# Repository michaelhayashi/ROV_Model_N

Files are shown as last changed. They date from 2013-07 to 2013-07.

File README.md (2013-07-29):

ROV_Model_N
===========

Purdue IEEE ROV Team project files

All of the electrical and code files are provided here free of charge for enthusiasts to modify, hack, fix, and do whatever to under OSHW. All files are given without any guarantee.

If anyone does have a cool idea about how to reuse/repurpose any of this hardware, or notices any glaring issues with it, let us know at purduerov@gmail.com

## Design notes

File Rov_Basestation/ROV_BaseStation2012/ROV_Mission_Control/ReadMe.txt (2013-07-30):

========================================================================
    APPLICATION : ROV_Mission_Control Project Overview
========================================================================

AppWizard has created this ROV_Mission_Control Application for you.  

This file contains a summary of what you will find in each of the files that
make up your ROV_Mission_Control application.

ROV_Mission_Control.vcxproj
    This is the main project file for VC++ projects generated using an Application Wizard. 
    It contains information about the version of Visual C++ that generated the file, and 
    information about the platforms, configurations, and project features selected with the
    Application Wizard.

ROV_Mission_Control.vcxproj.filters
    This is the filters file for VC++ projects generated using an Application Wizard. 
    It contains information about the association between the files in your project 
    and the filters. This association is used in the IDE to show grouping of files with
    similar extensions under a specific node (for e.g. ".cpp" files are associated with the
    "Source Files" filter).

ROV_Mission_Control.cpp
    This is the main application source file.
    Contains the code to display the form.

Form1.h
    Contains the implementation of your form class and InitializeComponent() function.

AssemblyInfo.cpp
    Contains custom attributes for modifying assembly metadata.

/////////////////////////////////////////////////////////////////////////////
Other standard files:

StdAfx.h, StdAfx.cpp
    These files are used to build a precompiled header (PCH) file
    named ROV_Mission_Control.pch and a precompiled types file named StdAfx.obj.

/////////////////////////////////////////////////////////////////////////////

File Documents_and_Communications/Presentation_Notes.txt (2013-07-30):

CAUTION: The PowerPoint presentation is for practice purposes only! The presentation should be given extemporaneously using only the vehicle and binders as aids.

Schedule:
Judges Introduce Themselves
We Introduce ourselves individually
  Name
  Year (going in to)
  Years on team
  What "team" you worked on (electrical/mechanical/communications/etc)
Hand judges their binders

Presenter #1 (Team spokesperson)
  Introduction
  Mission Theme
  Intro to Model N
    "ground up for mission" speech
Presenter #2 (Co-lead ME)
  Manipulator
  Measuring Tool
  Turning Motors
  Thrusters
Presenter #3 (Co-lead ME)
  Electronics Box
  Frame
  Cameras
Presenter #4 (Mechanical assembler)
  Buoyancy & Ballast
  Tether
  Pneumatics
Presenter #5 (Hardware EE)
  Transmissometer
  Electronics
Presenter #6 (Coding CompE)
  Software
    Main board & Basestation
    GUI
Presenter #7 (Pilot & CompE)
  Software
    Controls & Piloting
Presenter *8 (Team Captain)
  Expenses
  Scheduling
  Safety
  Outreach
  Acknowledgements

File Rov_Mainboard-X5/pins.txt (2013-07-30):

Pins we maybe can't use
PC14	> to other external oscilator
PC15 

PA13	> swd programming pins
PA14

PB9	> Audio SCA & SCL
PB6 

PC7	
PC10	> i2s3 
PC12
PA4

PD4	> audio reset

PC3	> PDM out >Double check these!
PC4	

PC3	> PDM out
PB10	> CLk in

PA9	> USB OTG	
PA11
PA12
PA10

PC0	> OTG Power

PD5	> OTH Over current

PA0	> wake up button

PA7	> SPI1 mosi
PA5	> spi1 sck

PE3	>cs spi????????
PA6	> spi1 miso

PE0	> MEMS init
PE1

PD12	> Greeb Led
PD13	> Orange Led
PD14	> Red Led
PD15	> Blue Led

11:60 reduction

Pins we need for things (not specific)

Already on discovery 
SPI1 - onboard accelerometer SPI1: PA7, PA6, PA5, Enable x2: PE0, PE1, why PE3 is needed is unknown
NRST - already implemented - NRST
Debug Led - can use ones on dev board - PD12, PD13, PD14, PD15

Need to put on board
i2c1 - IMU  - PB8, PB7
4x GPIO - for water detection  - Input floating: PD0, PC12, PC11, PC10
1x PWM - Turner motors - TIM1: PE9, PE11, PE13, PE14 - May not need all!
2x GPIO - motor selection - Output push pull: PE8, PE7
1x GPIO for fuse blown - Input floating:PE10
SPI2 - for solenoid selection - SPI2: PB15, PB10, PD3, PD2
5x ADC - for power sensing - ADC1: PA1, PA4, PB0, PB1, PC5
2x uart - 1 for tether - Usart2: PD6, PA2 
Usart6: PC7, PC6 - Motor bus also need PC8, PC9
2x GPIO - for camera selection PC11, PC12

Pb5 for MOTOR DIR

4x Extra GIPO: PD7, PE6, PE4, PE2

296-22711-6-ND - shift register
BCV46

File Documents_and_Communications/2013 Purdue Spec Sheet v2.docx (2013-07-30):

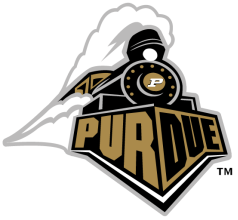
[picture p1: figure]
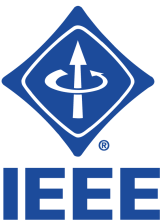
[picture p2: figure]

Purdue University IEEE ROV Team

West Lafayette, Indiana, USA

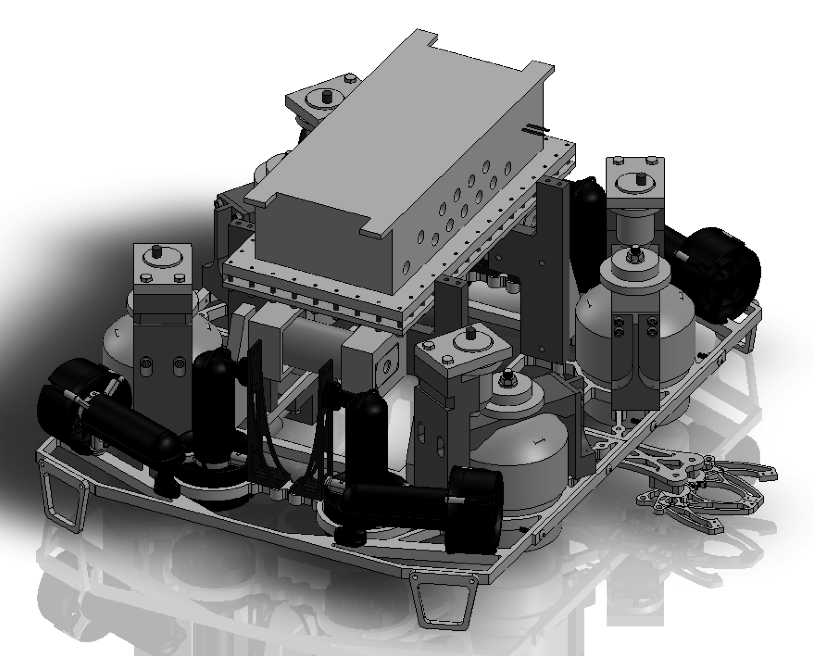
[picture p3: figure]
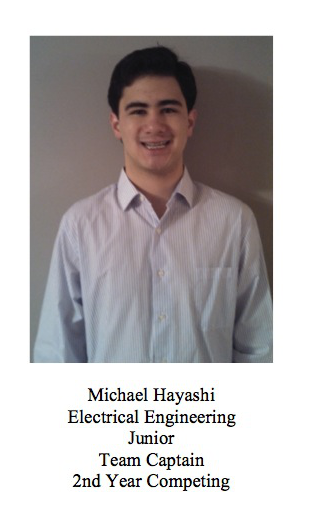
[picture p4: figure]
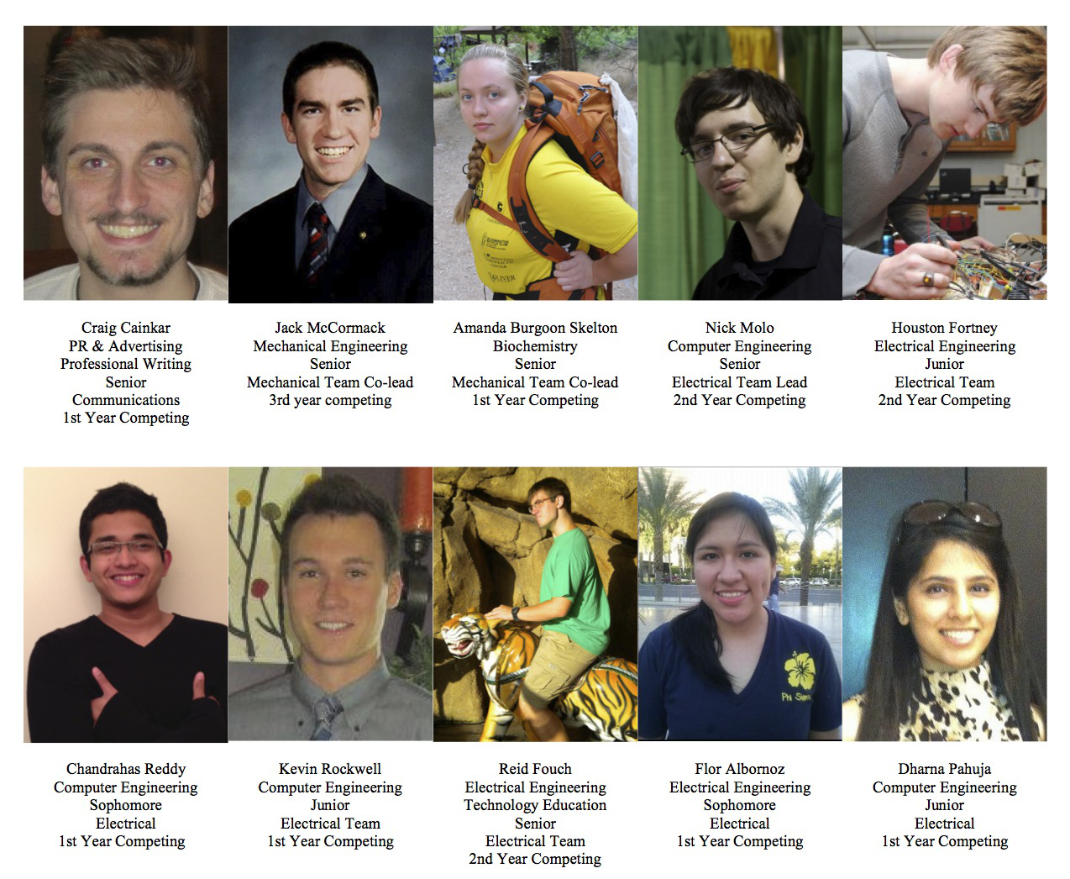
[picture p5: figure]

Total Cost of ROV: $20,758.90 USD Total Weight in Air: 19.0 kg

Overall Dimensions: 71 cm x 69 cm x 51 cm

Primary Materials: aluminum, stainless steel, polyoxymethylene (delrin), high-density polyethylene, polycarbonate

Special Features: immense power to weight ratio, lightweight MIC 6 aluminum frame, high-accuracy length measuring tool, single fixed manipulator for simplicity, entirely custom onboard electronics system and software

Key Safety Features: shrouds on all propellers, plastic propellers, complete FEA analysis with a safety factor of 2,

all electrical wiring sealed with liquid electrical tape and heat shrink, multiple fuses throughout electrical system, emergency quick release pneumatic valve

Model N

Distance Traveled: 2915 KM

Year Competing: 5th Year

2012 Finish: 2nd Place

Range of Grade Levels:

Sophmore to Senior

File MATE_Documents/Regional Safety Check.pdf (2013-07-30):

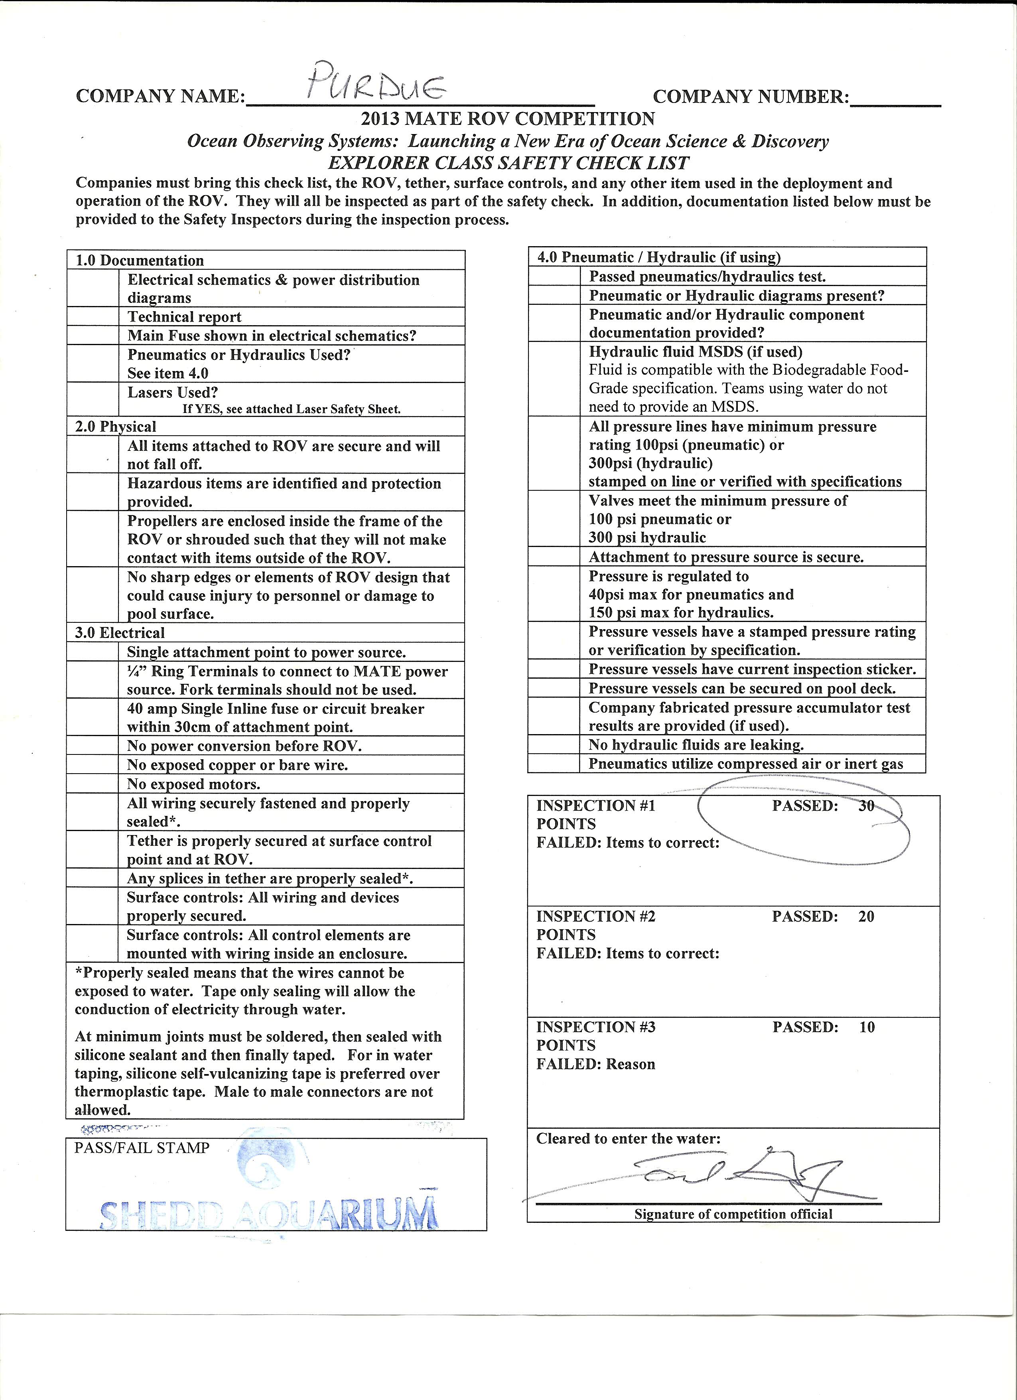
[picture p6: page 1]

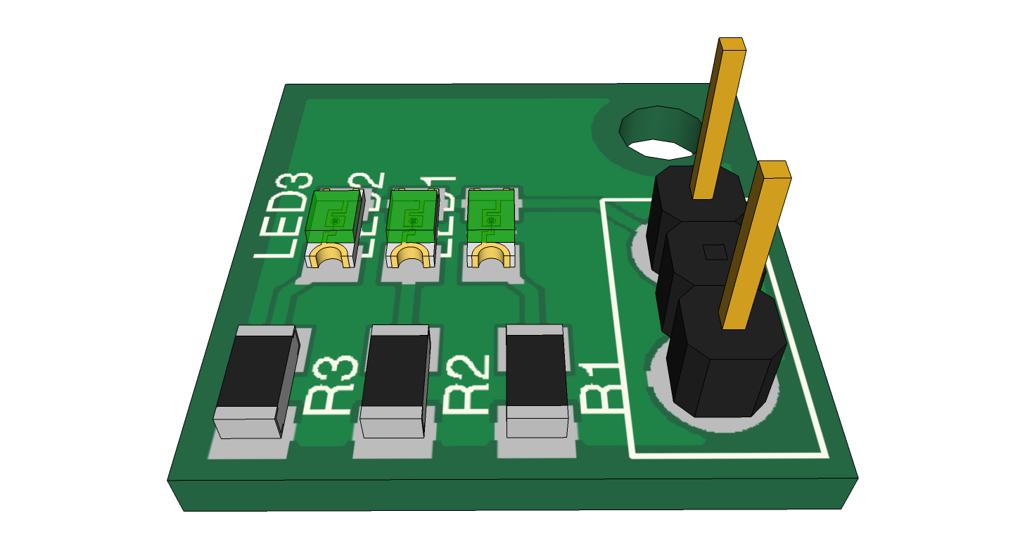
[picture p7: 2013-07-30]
Electronics/Transmissometer_TX_Board/TX Board.png

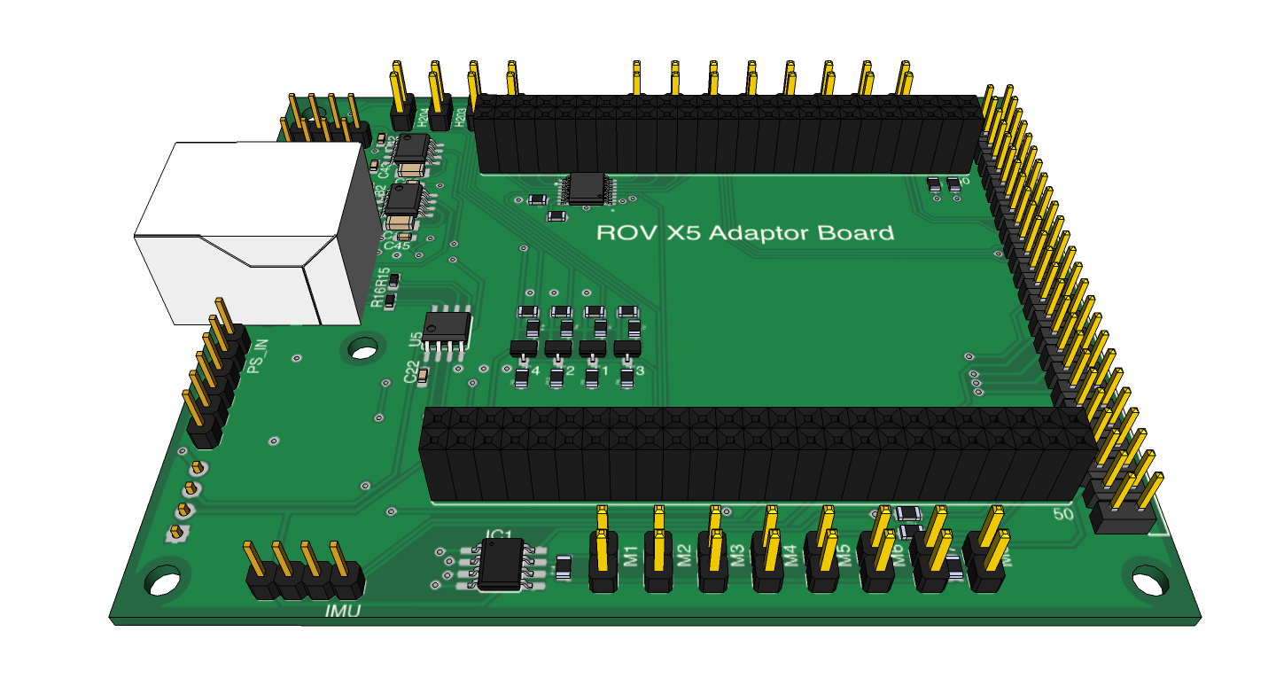
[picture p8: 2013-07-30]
Electronics/Microcontroller_Adaptor_Board/Adaptor.png

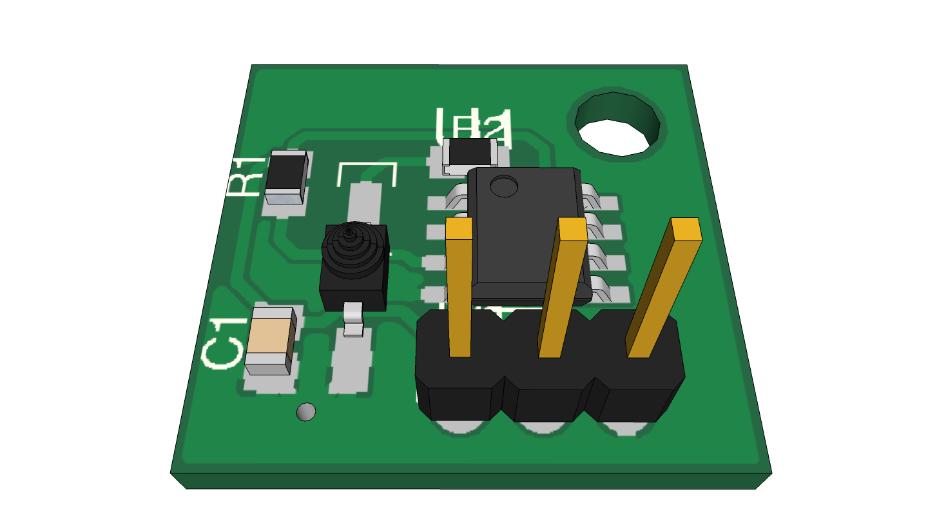
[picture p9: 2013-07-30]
Electronics/Transmissometer_RX_Board/Transmissometer_RX_Boardv1.png

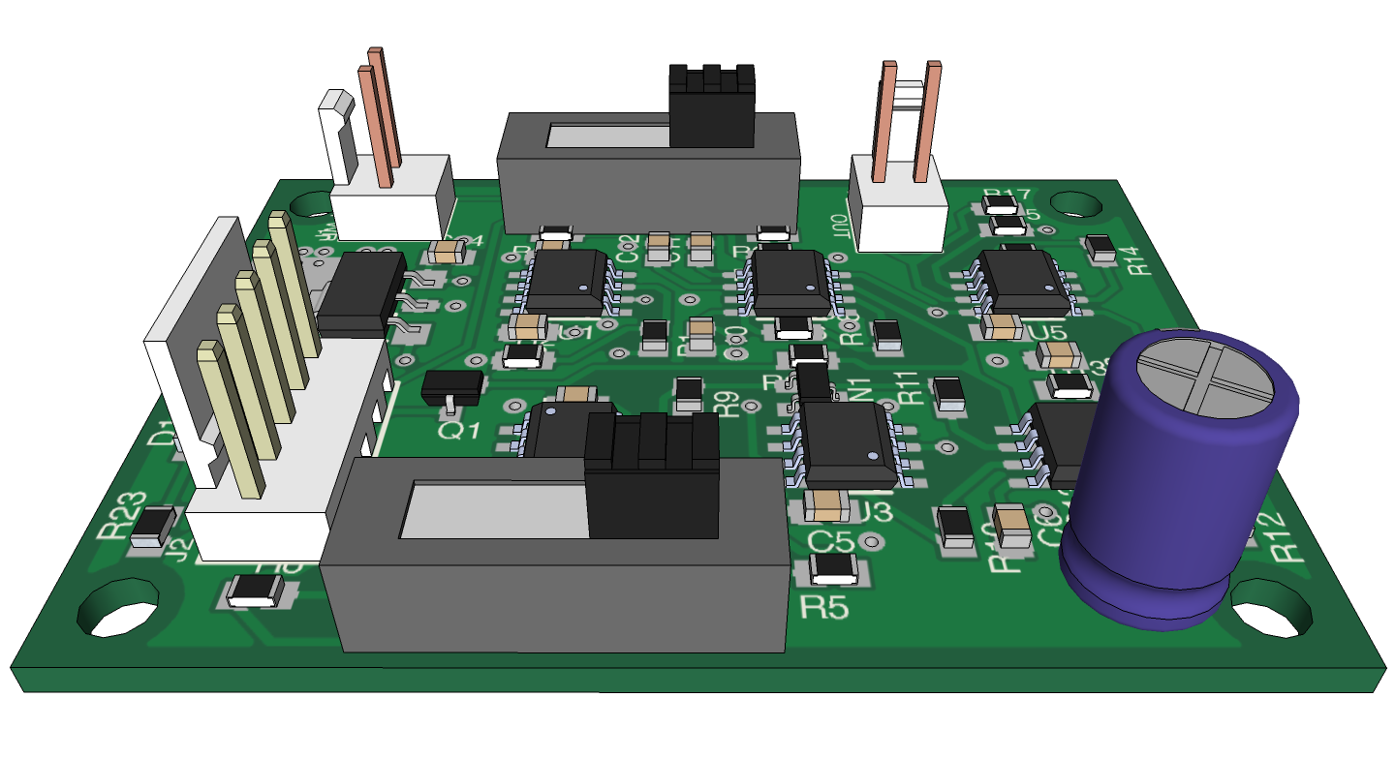
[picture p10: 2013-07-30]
Electronics/Transmissometer_Surface_Board/Top.png

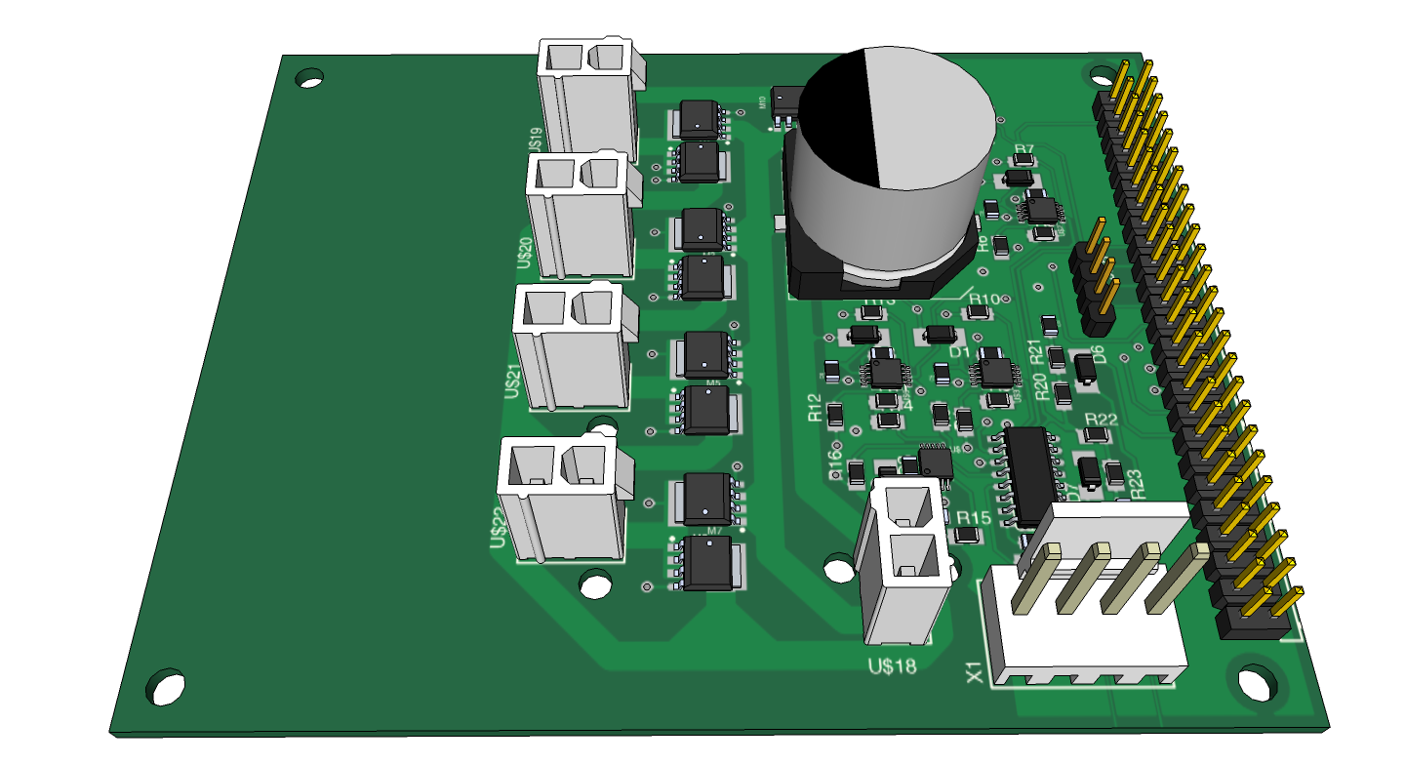
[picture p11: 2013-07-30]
Electronics/Application_Board/Application_Board.png

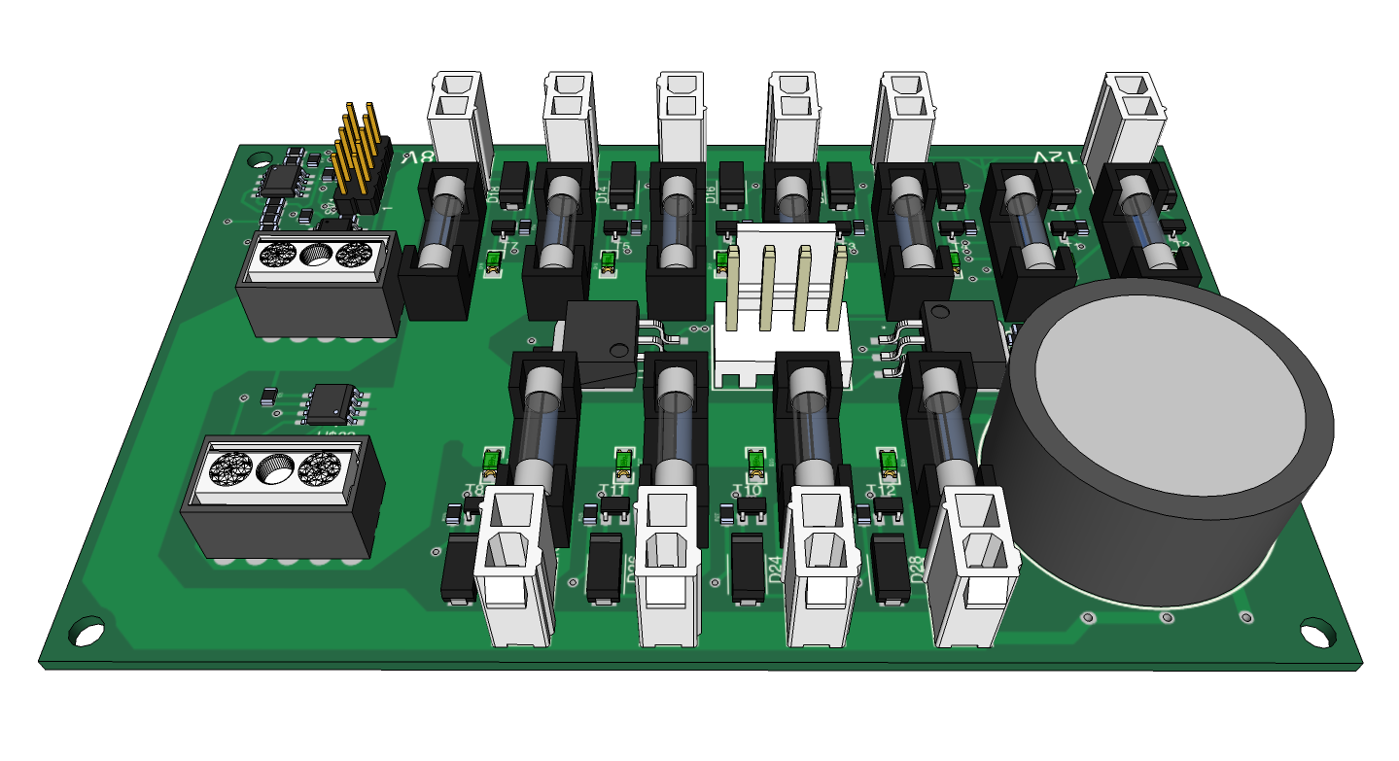
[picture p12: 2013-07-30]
Electronics/Power_Board/Power Board.png

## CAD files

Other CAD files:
Electronics/Application_Board/Application_Board.skp
Electronics/Microcontroller_Adaptor_Board/Adaptor.skp
Electronics/Power_Board/Power Board.skp
Electronics/ROV_2013_SketchUp/0805.skp
Electronics/ROV_2013_SketchUp/0805~.skp
Electronics/ROV_2013_SketchUp/10-MSOP.skp
Electronics/ROV_2013_SketchUp/10-MSOP~.skp
Electronics/ROV_2013_SketchUp/1X02.skp
Electronics/ROV_2013_SketchUp/1X02_XTRA_BIG.skp
Electronics/ROV_2013_SketchUp/1X02_XTRA_BIG~.skp
Electronics/ROV_2013_SketchUp/1X02~.skp
Electronics/ROV_2013_SketchUp/1X03.skp
Electronics/ROV_2013_SketchUp/1X04.skp
Electronics/ROV_2013_SketchUp/1X04_NO_SILK.skp
Electronics/ROV_2013_SketchUp/1X04~.skp
Electronics/ROV_2013_SketchUp/1X06.skp
Electronics/ROV_2013_SketchUp/1X06~.skp
Electronics/ROV_2013_SketchUp/2-3SW.skp
Electronics/ROV_2013_SketchUp/2-3SW~.skp
Electronics/ROV_2013_SketchUp/22-23-2021.skp
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

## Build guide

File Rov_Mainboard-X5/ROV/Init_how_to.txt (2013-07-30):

1. Port RCC

RCC_AHB1PeriphClockCmd(RCC_AHB1Periph_GPIOX, ENABLE);

2. Periph RCC

 - Tim
	RCC_APB1PeriphClockCmd(RCC_APB1Periph_TIMX, ENABLE );
	RCC_APB2PeriphClockCmd(RCC_APB2Periph_TIM9, ENABLE ); //TIM9 and TIM8 are on APB2

 - USART
	RCC_APB1PeriphClockCmd(RCC_APB1Periph_USART3, ENABLE);

3. GPIO Enable

 - PWM
	GPIO_InitTypeDef GPIO_InitStructure;
	
	GPIO_InitStructure.GPIO_Pin =  GPIO_Pin_X;// | GPIO_Pin_X //more for channels
	GPIO_InitStructure.GPIO_Mode = GPIO_Mode_AF;
	GPIO_InitStructure.GPIO_OType = GPIO_OType_PP;
	GPIO_InitStructure.GPIO_PuPd = GPIO_PuPd_NOPULL;
	GPIO_InitStructure.GPIO_Speed = GPIO_Speed_100MHz;
	
	GPIO_Init(GPIOX, &GPIO_InitStructure);

	GPIO_PinAFConfig(GPIOX, GPIO_PinSourceX, GPIO_AF_TIMX);// put in order of what channel it is
	GPIO_PinAFConfig(GPIOX, GPIO_PinSourceX, GPIO_AF_TIMX);

 - OUTPUT
	GPIO_InitTypeDef GPIO_InitStructure;

	GPIO_InitStructure.GPIO_Pin = GPIO_Pin_X;
        GPIO_InitStructure.GPIO_Mode = GPIO_Mode_OUT;
        GPIO_InitStructure.GPIO_OType = GPIO_OType_PP;
        GPIO_InitStructure.GPIO_PuPd = GPIO_PuPd_NOPULL;
	GPIO_InitStructure.GPIO_Speed = GPIO_Speed_100MHz;
	GPIO_Init(GPIOX, &GPIO_InitStructure);

 - INPUT
	//not figured out yet...

 - USART
	GPIO_InitTypeDef GPIO_InitStructure;

	GPIO_InitStructure.GPIO_Pin =  GPIO_Pin_X | GPIO_Pin_X;
	GPIO_InitStructure.GPIO_Mode = GPIO_Mode_AF;
	GPIO_InitStructure.GPIO_OType = GPIO_OType_PP;
	GPIO_InitStructure.GPIO_PuPd = GPIO_PuPd_NOPULL;
	GPIO_InitStructure.GPIO_Speed = GPIO_Speed_100MHz;
	GPIO_Init(GPIOX, &GPIO_InitStructure);

	GPIO_PinAFConfig(GPIOX, GPIO_PinSourceX, GPIO_AF_USART3); //note pretty much same as PWM
	GPIO_PinAFConfig(GPIOX, GPIO_PinSourceX, GPIO_AF_USART3); //Except for here

4. Timer enable

	PrescalerValue = //set something

	TIM_TimeBaseInitTypeDef TIM_TimeBaseInitStruct;
	
	TIM_OCInitTypeDef TIM_OCInitStruct;

	TIM_TimeBaseStructInit( &TIM_TimeBaseInitStruct );
	TIM_TimeBaseInitStruct.TIM_ClockDivision = TIM_CKD_DIV4;
	TIM_TimeBaseInitStruct.TIM_Period =1000 - 1;   // 0..999
	TIM_TimeBaseInitStruct.TIM_Prescaler = PrescalerValue; // Div 240
        TIM_TimeBaseInit( TIMX, &TIM_TimeBaseInitStruct );

        TIM_OCStructInit( &TIM_OCInitStruct );
	TIM_OCInitStruct.TIM_OutputState = TIM_OutputState_Enable;
	TIM_OCInitStruct.TIM_OCMode = TIM_OCMode_PWM1;
	TIM_OCInitStruct.TIM_Pulse = 500;

	TIM_OC1Init( TIMX, &TIM_OCInitStruct ); //will use 2 channels on all timers but tim 8, 
	TIM_OC2Init( TIMX, &TIM_OCInitStruct ); //in that case will use 3 (LED)
	TIM_OC3Init( TIMX, &TIM_OCInitStruct );

	TIM_Cmd( TIMX, ENABLE );
	
5. Periph Init
	USART_InitTypeDef USART_InitStructure;
	
	USART_InitStructure.USART_BaudRate = 9600;
	USART_InitStructure.USART_WordLength = USART_WordLength_8b;
	USART_InitStructure.USART_StopBits = USART_StopBits_1;
	USART_InitStructure.USART_Parity = USART_Parity_No;
	USART_InitStructure.USART_HardwareFlowControl = USART_HardwareFlowControl_None;
	
	USART_InitStructure.USART_Mode = USART_Mode_Rx | USART_Mode_Tx;
	
	USART_Init(USART3, &USART_InitStructure);

	USART_Cmd(USART3, ENABLE);

Shift register notes -

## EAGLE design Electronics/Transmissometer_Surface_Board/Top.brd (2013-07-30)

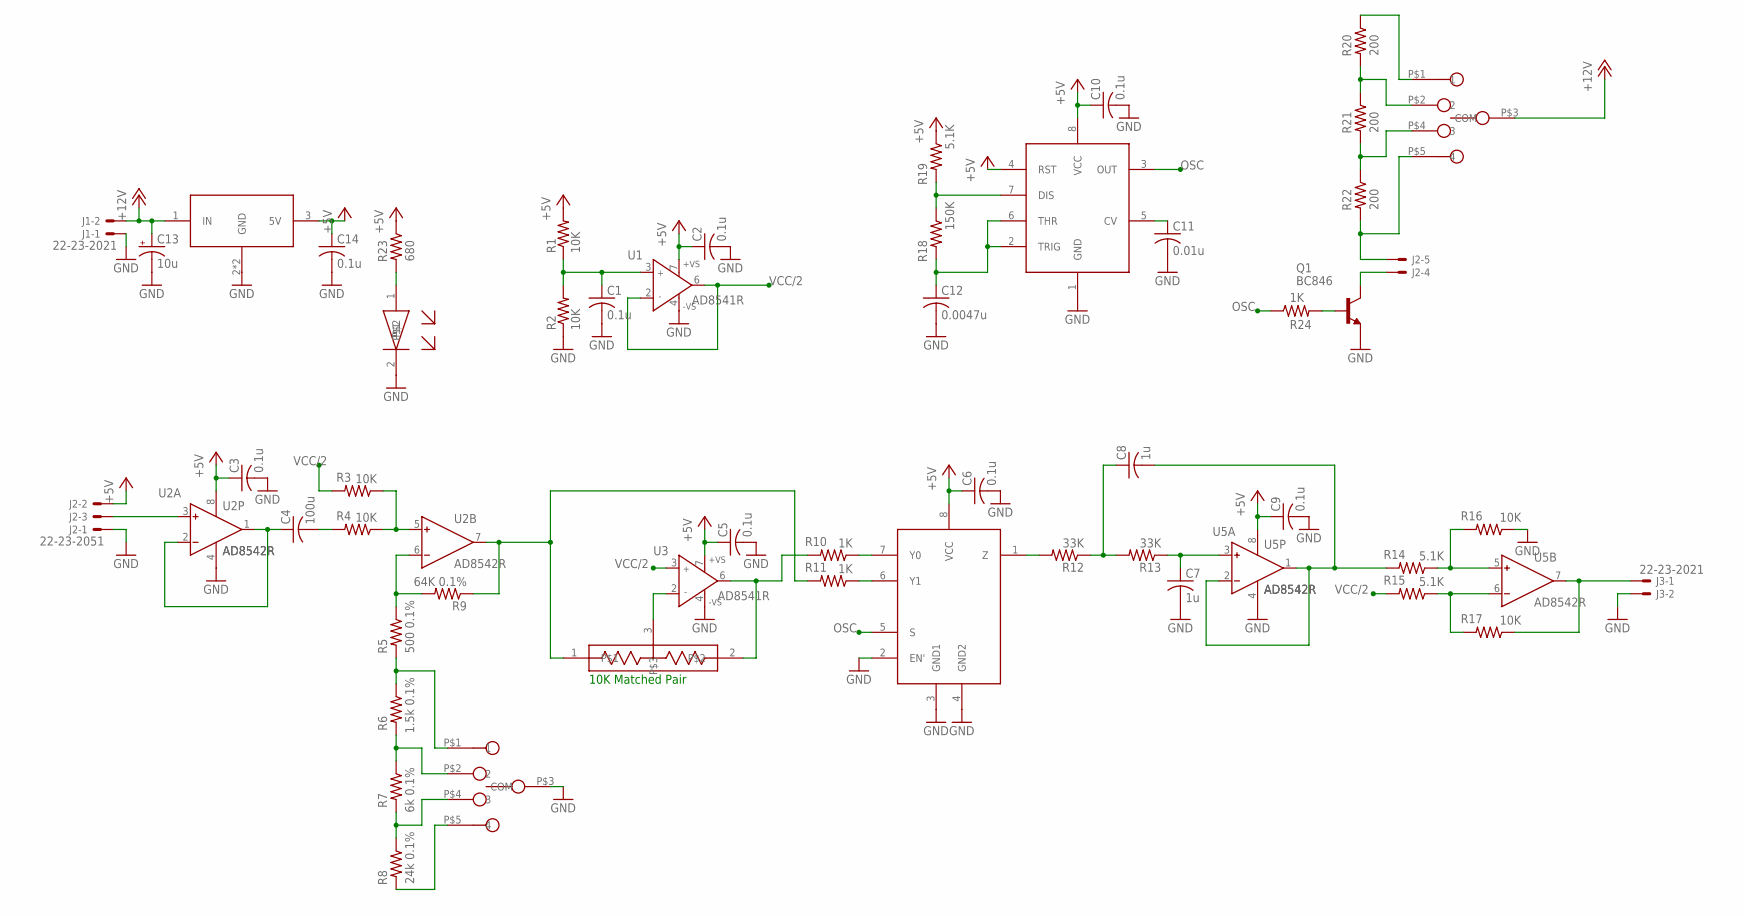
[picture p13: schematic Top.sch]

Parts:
C1, C2, C3, C5, C6, C9, C10, C14: 0.1u; C0805
C4: 100u; C1206
C7, C8: 1u; C0805
C11: 0.01u; C0805
C12: 0.0047u; C0805
C13: 10u; E2-5
D1: LGN971; R1206
J1, J3: 22-23-2021
J2: 22-23-2051
Q1: BC846; SOT23
R1, R2, R3, R4, R16, R17: 10K; R0805
R5: 500 0.1%; R0805
R6: 1.5k 0.1%; R0805
R7: 6k 0.1%; R0805
R8: 24k 0.1%; R0805
R9: 64K 0.1%; R0805
R10, R11, R24: 1K; R0805
R12, R13: 33K; R0805
R14, R15, R19: 5.1K; R0805
R18: 150K; R0805
R20, R21, R22: 200; R0805
R23: 680; R0805
RN1: MPMT2002; SOT23
SW1, SW2: STS1400; 2-3SW
U1, U3: AD8541R; SO8
U2, U5: AD8542R; SO8
U4: 74LVC1G53; SOP08
U6: NA555; SO8
U7: UA78M05CDCYR; SOT223-W

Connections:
+5V: C2.1, C3.1, C5.1, C6.1, C9.1, C10.1, C14.1, J2.2, R1.2, R19.1, R23.1, U1.7 (+VS), U2.8 (V+), U3.7 (+VS), U4.8 (VCC), U5.8 (V+), U6.4 (RST), U6.8 (VCC), U7.3 (5V)
+12V: C13.+, J1.2, SW2.P$3 (COM), U7.1 (IN)
GND: C1.2, C2.2, C3.2, C5.2, C6.2, C7.2, C9.2, C10.2, C11.2, C12.2, C13.-, C14.2, D1.2, J1.1, J2.1, J3.2, Q1.2 (E), R2.1, R16.1, SW1.P$3 (COM), U1.4 (-VS), U2.4 (V-), U3.4 (-VS), U4.2 (EN'), U4.3 (GND1), U4.4 (GND2), U5.4 (V-), U6.1 (GND), U7.2 (GND), U7.4 (GND)
unnamed: C1.1, R1.1, R2.2, U1.3 (IN+)
unnamed: C4.1, U2.1 (OUT), U2.2 (IN-)
unnamed: C4.2, R4.2
unnamed: R3.1, R4.1, U2.5 (IN+)
unnamed: R5.1, R9.2, U2.6 (IN-)
unnamed: R9.1, R11.2, RN1.1, U2.7 (OUT)
unnamed: R7.2, R8.1, SW1.P$4 (3)
unnamed: R6.2, R7.1, SW1.P$2 (2)
unnamed: R5.2, R6.1, SW1.P$1 (1)
unnamed: RN1.3, U3.2 (IN-)
unnamed: R10.2, RN1.2, U3.6 (OUT)
unnamed: R10.1, U4.7 (Y0)
unnamed: R11.1, U4.6 (Y1)
unnamed: C8.1, R12.1, R13.2
unnamed: C7.1, R13.1, U5.3 (IN+)
unnamed: C8.2, R14.2, U5.1 (OUT), U5.2 (IN-)
unnamed: R18.1, R19.2, U6.7 (DIS)
unnamed: R14.1, R16.2, U5.5 (IN+)
unnamed: R15.1, R17.2, U5.6 (IN-)
unnamed: J3.1, R17.1, U5.7 (OUT)
unnamed: D1.1, R23.2
unnamed: R12.2, U4.1 (Z)
unnamed: C12.1, R18.2, U6.2 (TRIG), U6.6 (THR)
unnamed: Q1.1 (B), R24.2
unnamed: J2.5, R22.2, SW2.P$5 (4)
unnamed: C11.1, U6.5 (CV)
unnamed: J2.4, Q1.3 (C)
unnamed: J2.3, U2.3 (IN+)
unnamed: R8.2, SW1.P$5 (4)
unnamed: R21.2, R22.1, SW2.P$4 (3)
unnamed: R20.2, R21.1, SW2.P$2 (2)
unnamed: R20.1, SW2.P$1 (1)
OSC: R24.1, U4.5 (S), U6.3 (OUT)
VCC/2: R3.2, R15.2, U1.2 (IN-), U1.6 (OUT), U3.3 (IN+)

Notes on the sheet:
10K Matched Pair

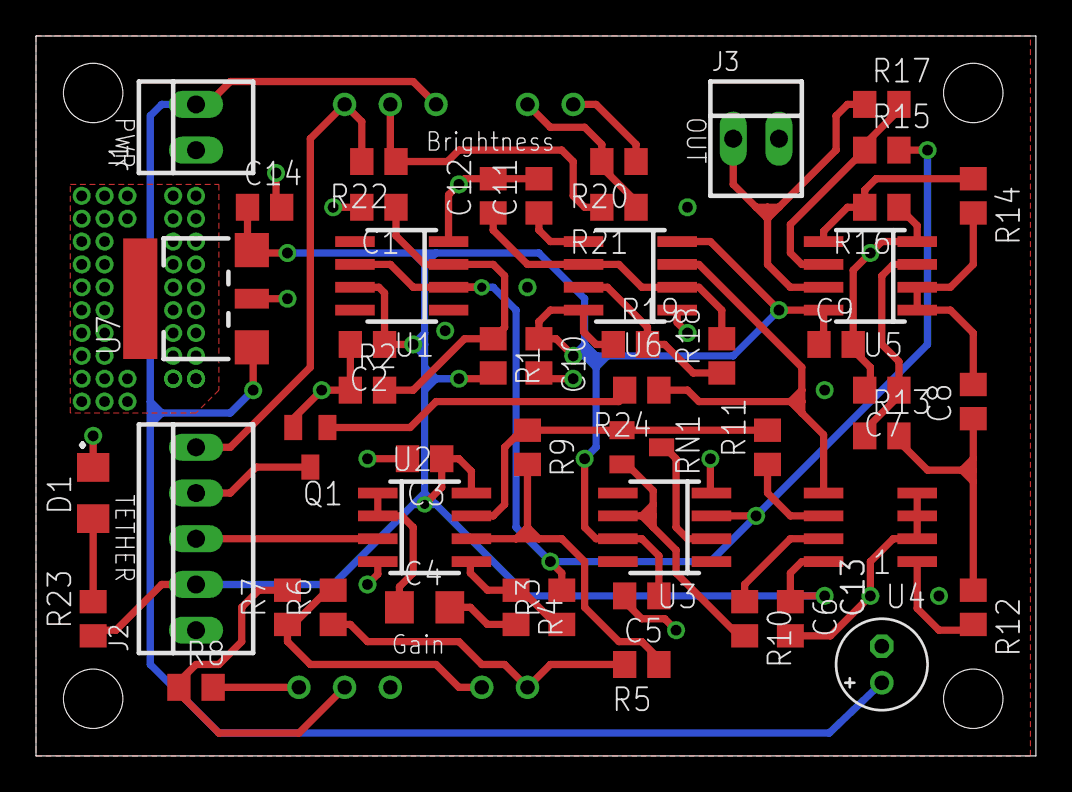
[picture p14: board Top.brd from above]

Board: 2 copper layers, 55.5 x 40.0 mm, 57 parts (0 on the bottom side), 37 nets.

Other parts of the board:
U$1, U$2, U$3, U$4: STAND-OFF

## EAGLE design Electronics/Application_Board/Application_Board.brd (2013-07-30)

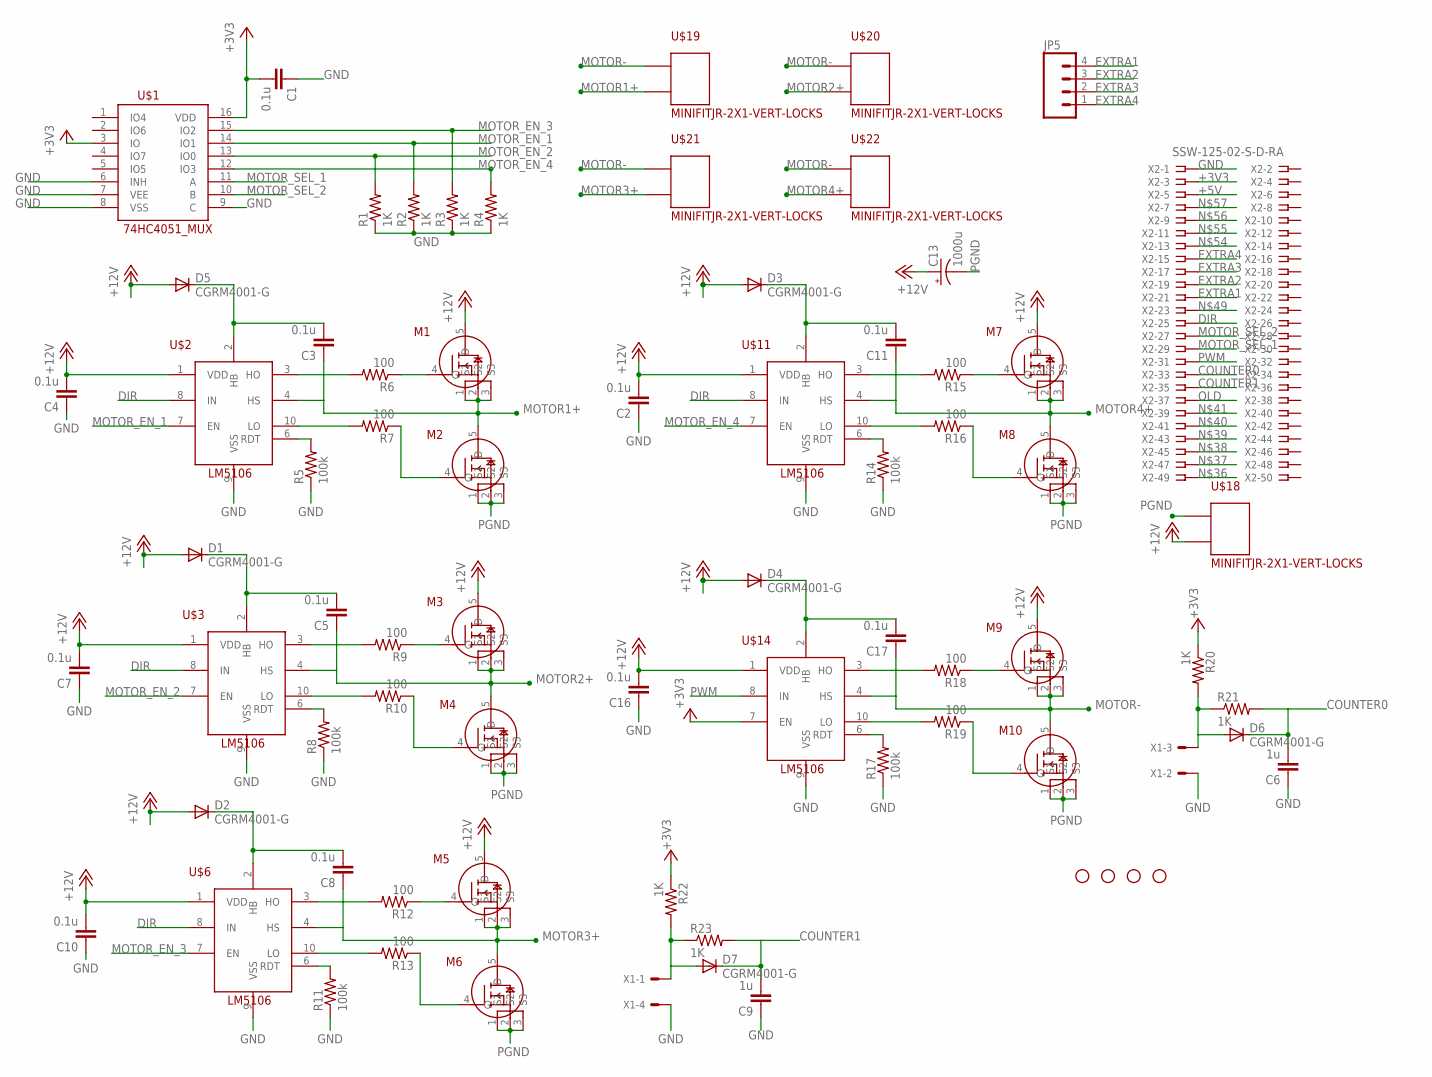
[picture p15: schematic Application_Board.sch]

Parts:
C1, C2, C3, C4, C5, C7, C8, C10, C11, C16, C17: 0.1u; 0805
C6, C9: 1u; 0805
C13: 1000u; UD-18X19,1_NICHICON
D1, D2, D3, D4, D5, D6, D7: CGRM4001-G; SOD-123_MINI-SMA
JP1, JP2, JP3, JP4: STAND-OFF
JP5: M041X04_NO_SILK; 1X04_NO_SILK
M1, M2, M3, M4, M5, M6, M7, M8, M9, M10: M; TO127P600X120-5N
R1, R2, R3, R4, R20, R21, R22, R23: 1K; R0805
R5, R8, R11, R14, R17: 100k; R0805
R6, R7, R9, R10, R12, R13, R15, R16, R18, R19: 100; R0805
U$1: 74HC4051_MUX; SO16
U$2, U$3, U$6, U$11, U$14: LM5106MMSMD-MSOP; 10-MSOP
U$18, U$19, U$20, U$21, U$22: MINIFITJR-2X1-VERT-LOCKS; 5566-02A2
X1: KK-156-4
X2: SSW-125-02-S-D-RA; TSW-125-02-S-D-RA

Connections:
+3V3: C1.2, R20.1, R22.1, U$1.3 (IO), U$1.16 (VDD), U$14.7 (EN), X2.3
+5V: X2.5
+12V: C2.2, C4.2, C7.2, C10.2, C13.+, C16.2, D1.A, D2.A, D3.A, D4.A, D5.A, M1.5 (D), M3.5 (D), M5.5 (D), M7.5 (D), M9.5 (D), U$2.1 (VDD), U$3.1 (VDD), U$6.1 (VDD), U$11.1 (VDD), U$14.1 (VDD), U$18.P$2
COUNTER0: C6.2, D6.C, R21.2, X2.33
COUNTER1: C9.2, D7.C, R23.2, X2.35
DIR: U$2.8 (IN), U$3.8 (IN), U$6.8 (IN), U$11.8 (IN), X2.25
EXTRA1: JP5.4, X2.21
EXTRA2: JP5.3, X2.19
EXTRA3: JP5.2, X2.17
EXTRA4: JP5.1, X2.15
GND: C1.1, C2.1, C4.1, C6.1, C7.1, C9.1, C10.1, C16.1, R1.1, R2.1, R3.1, R4.1, R5.1, R8.1, R11.1, R14.1, R17.1, U$1.6 (INH), U$1.7 (VEE), U$1.8 (VSS), U$1.9 (C), U$2.9 (VSS), U$3.9 (VSS), U$6.9 (VSS), U$11.9 (VSS), U$14.9 (VSS), X1.2, X1.4, X2.1
MOTOR1+: C3.1, M1.1 (S1), M1.2 (S2), M1.3 (S3), M2.5 (D), U$2.4 (HS), U$19.P$2
MOTOR2+: C5.1, M3.1 (S1), M3.2 (S2), M3.3 (S3), M4.5 (D), U$3.4 (HS), U$20.P$2
MOTOR3+: C8.1, M5.1 (S1), M5.2 (S2), M5.3 (S3), M6.5 (D), U$6.4 (HS), U$21.P$2
MOTOR4+: C11.1, M7.1 (S1), M7.2 (S2), M7.3 (S3), M8.5 (D), U$11.4 (HS), U$22.P$2
MOTOR-: C17.1, M9.1 (S1), M9.2 (S2), M9.3 (S3), M10.5 (D), U$14.4 (HS), U$19.P$1, U$20.P$1, U$21.P$1, U$22.P$1
MOTOR_EN_1: R2.2, U$1.14 (IO1), U$2.7 (EN)
MOTOR_EN_2: R1.2, U$1.13 (IO0), U$3.7 (EN)
MOTOR_EN_3: R3.2, U$1.15 (IO2), U$6.7 (EN)
MOTOR_EN_4: R4.2, U$1.12 (IO3), U$11.7 (EN)
MOTOR_SEL_1: U$1.11 (A), X2.29
MOTOR_SEL_2: U$1.10 (B), X2.27
unnamed: C3.2, D5.C, U$2.2 (HB)
unnamed: R9.2, U$3.3 (HO)
unnamed: R10.2, U$3.10 (LO)
unnamed: M1.4 (G), R6.1
unnamed: R5.2, U$2.6 (RDT)
unnamed: C5.2, D1.C, U$3.2 (HB)
unnamed: R8.2, U$3.6 (RDT)
unnamed: M2.4 (G), R7.1
unnamed: M3.4 (G), R9.1
unnamed: M4.4 (G), R10.1
unnamed: R12.2, U$6.3 (HO)
unnamed: R13.2, U$6.10 (LO)
unnamed: C8.2, D2.C, U$6.2 (HB)
unnamed: R11.2, U$6.6 (RDT)
unnamed: M5.4 (G), R12.1
unnamed: M6.4 (G), R13.1
unnamed: R15.2, U$11.3 (HO)
unnamed: R16.2, U$11.10 (LO)
unnamed: C11.2, D3.C, U$11.2 (HB)
unnamed: R14.2, U$11.6 (RDT)
unnamed: M7.4 (G), R15.1
unnamed: M8.4 (G), R16.1
unnamed: R18.2, U$14.3 (HO)
unnamed: R19.2, U$14.10 (LO)
unnamed: C17.2, D4.C, U$14.2 (HB)
unnamed: R17.2, U$14.6 (RDT)
unnamed: M9.4 (G), R18.1
unnamed: M10.4 (G), R19.1
unnamed: D7.A, R22.2, R23.1, X1.1
unnamed: D6.A, R20.2, R21.1, X1.3
unnamed: R6.2, U$2.3 (HO)
unnamed: R7.2, U$2.10 (LO)
OLD: X2.37
PGND: C13.-, M2.1 (S1), M2.2 (S2), M2.3 (S3), M4.1 (S1), M4.2 (S2), M4.3 (S3), M6.1 (S1), M6.2 (S2), M6.3 (S3), M8.1 (S1), M8.2 (S2), M8.3 (S3), M10.1 (S1), M10.2 (S2), M10.3 (S3), U$18.P$1
PWM: U$14.8 (IN), X2.31

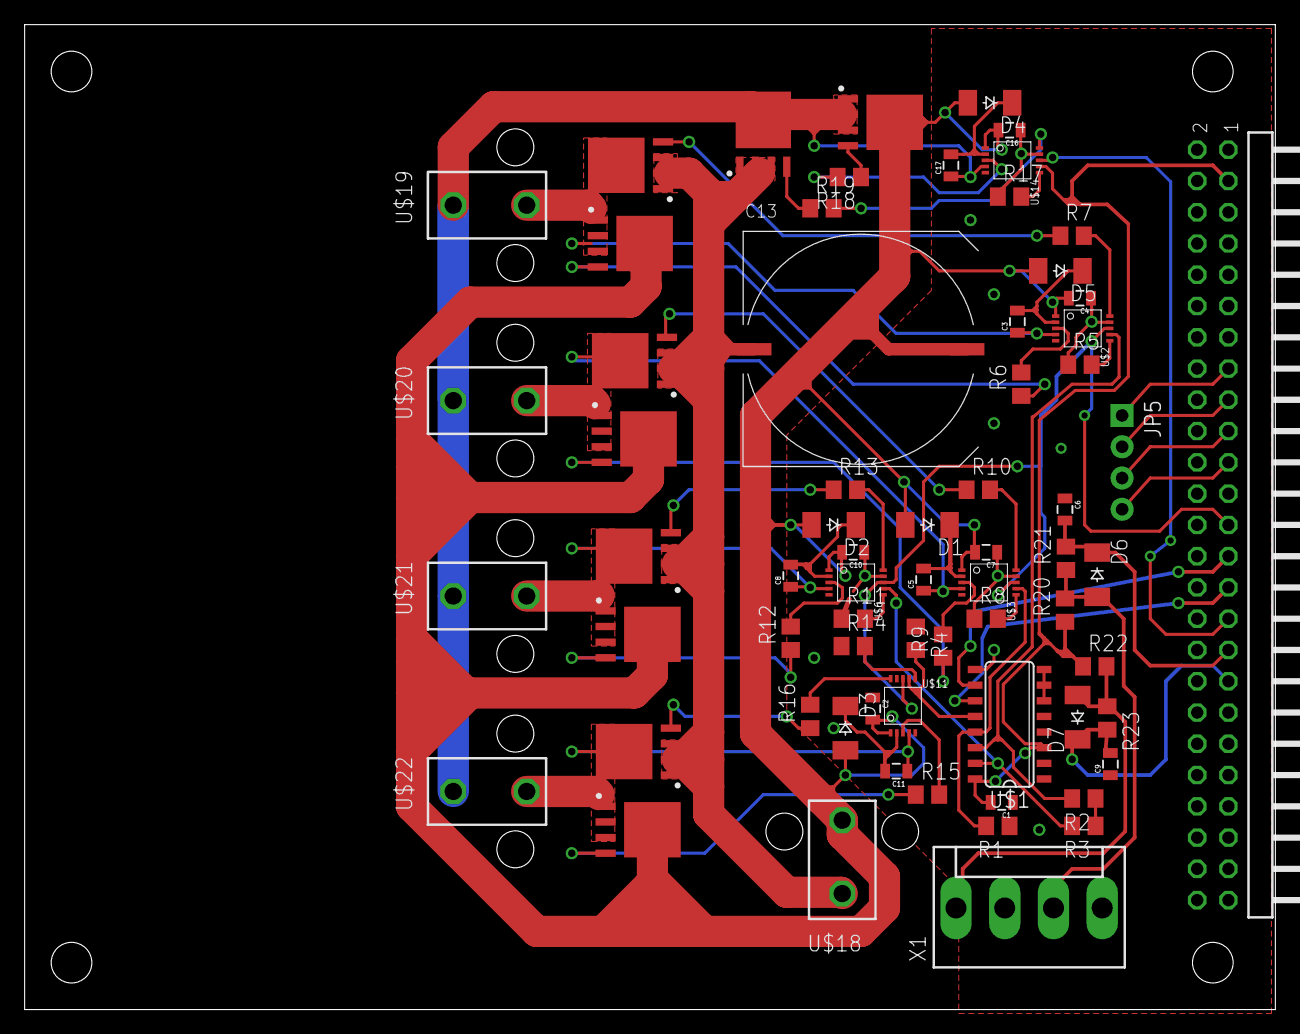
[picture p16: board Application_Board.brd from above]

Board: 2 copper layers, 101.6 x 80.0 mm, 72 parts (0 on the bottom side), 55 nets.

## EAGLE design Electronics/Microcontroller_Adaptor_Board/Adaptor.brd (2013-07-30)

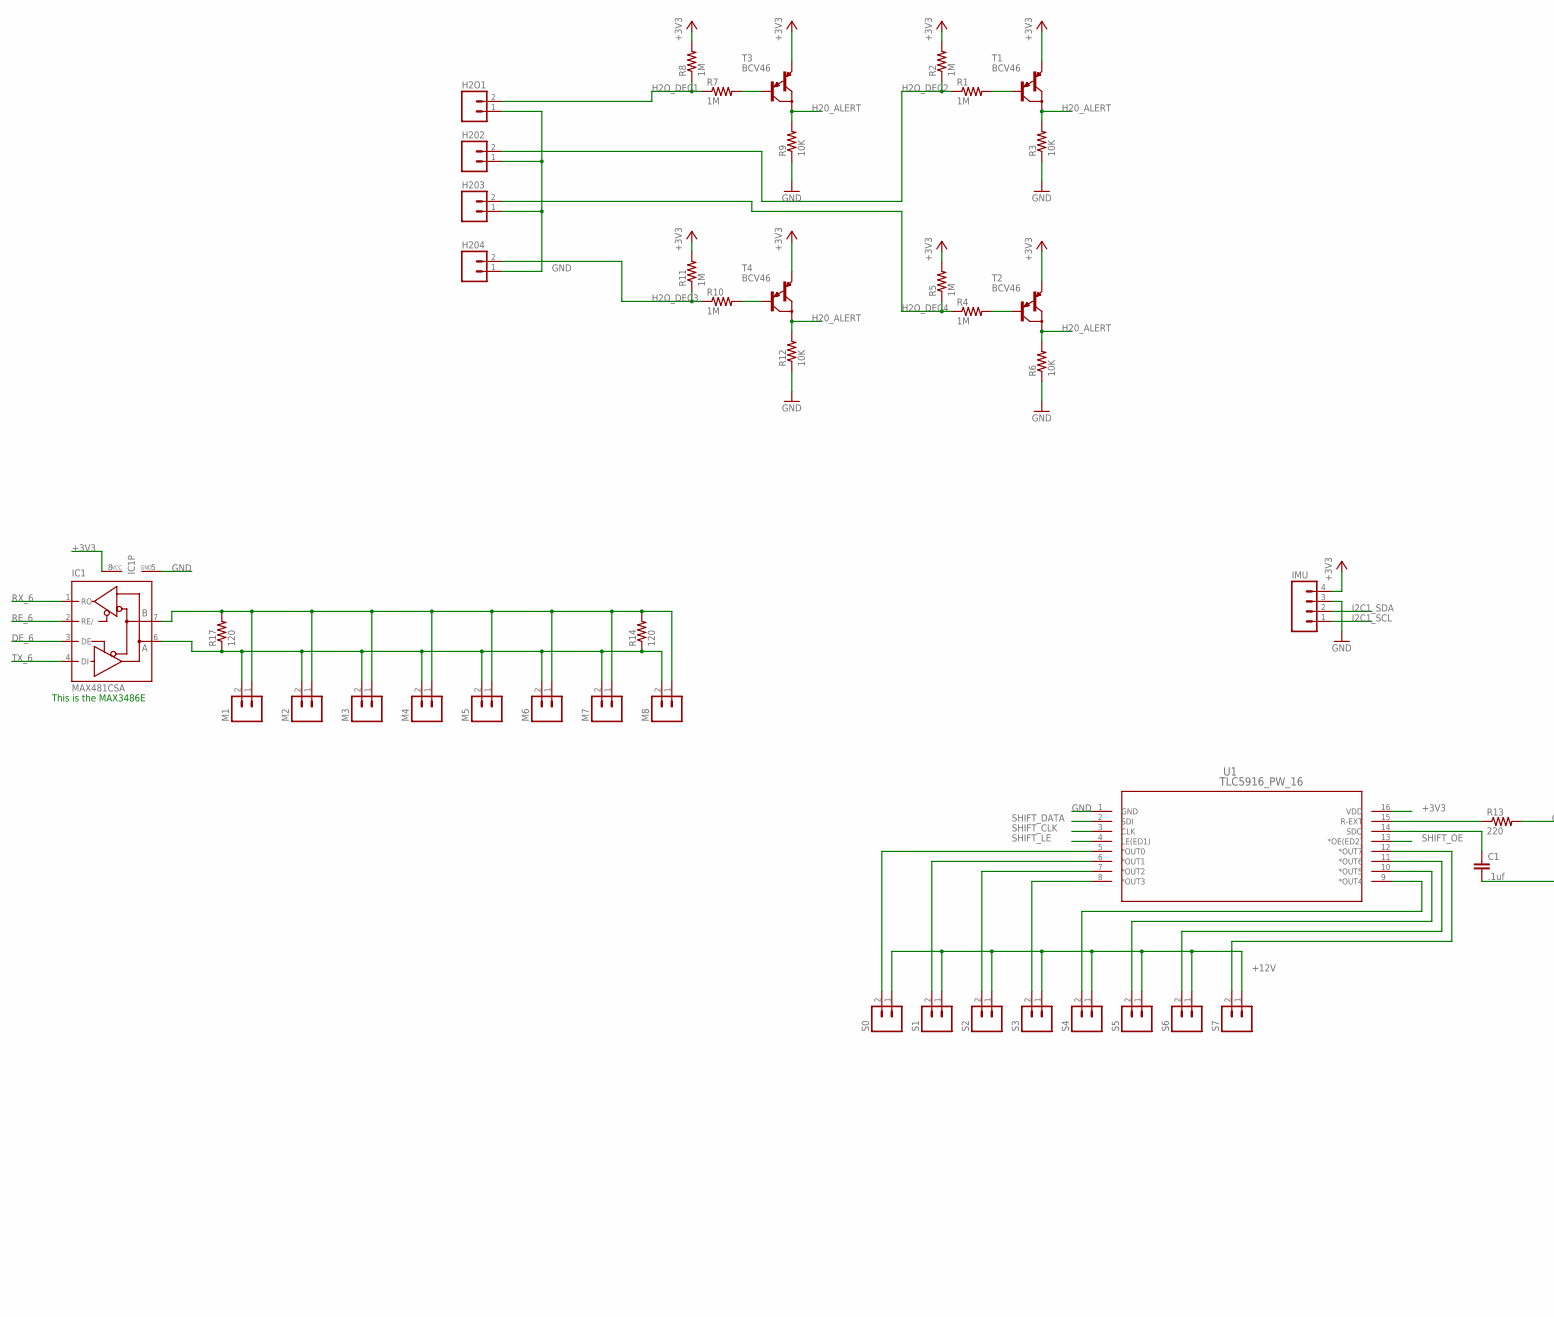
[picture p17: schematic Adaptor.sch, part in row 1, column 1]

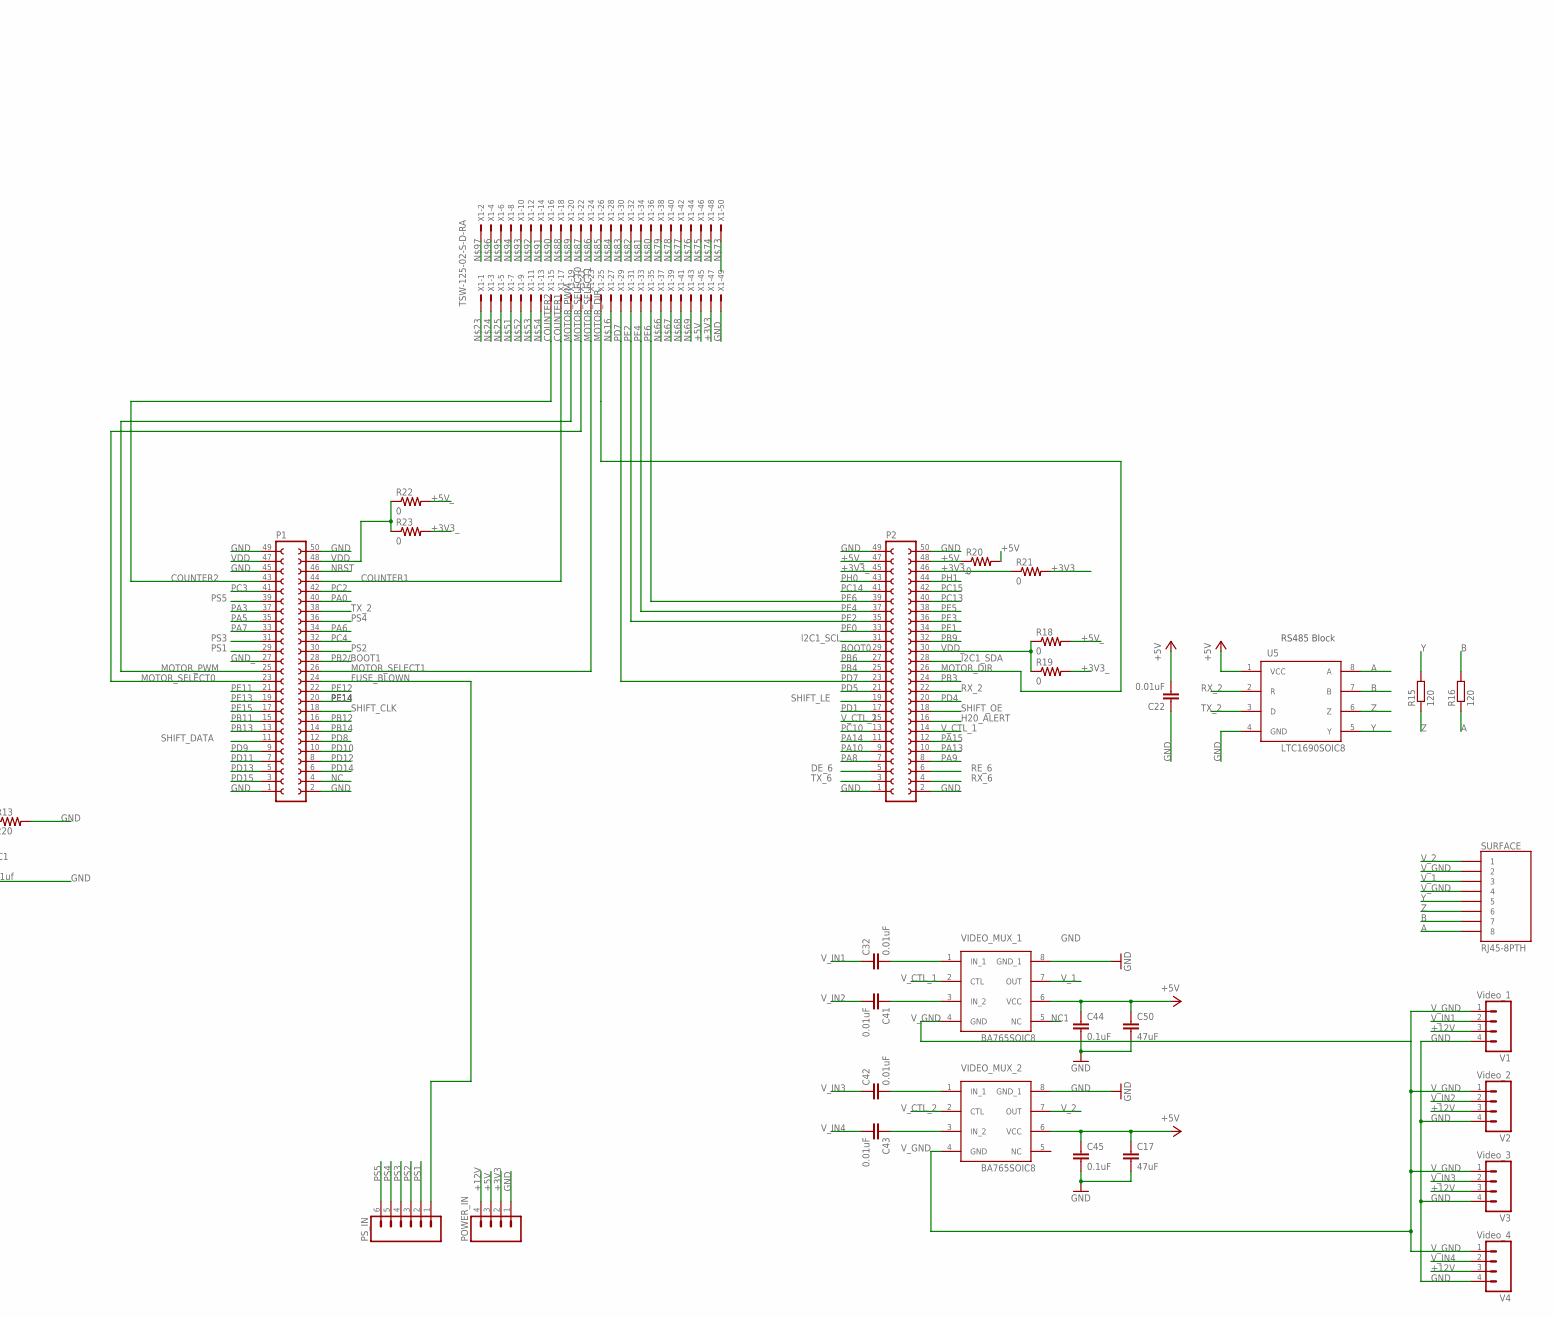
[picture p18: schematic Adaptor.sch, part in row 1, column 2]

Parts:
C1: .1uf; 0805
C17, C50: 47uF; C1206; PARTNO 490-5528-1-ND
C22, C32, C41, C42, C43: 0.01uF; C0603; PARTNO 478-1227-1-ND
C44, C45: 0.1uF; C0603; PARTNO 311-1344-1-ND
H2O1, H202, H203, H204: M02PTH; 1X02
IC1: MAX481CSA; SO08
IMU: M04PTH; 1X04
M1, M2, M3, M4, M5, M6, M7, M8: M02PTH; 1X02
P1, P2: FE25-2
POWER_IN: M04PTH; 1X04
PS_IN: M06SIP; 1X06
R1, R2, R4, R5, R7, R8, R10, R11: 1M; 0805
R3, R6, R9, R12: 10K; 0805
R13: 220; 0805
R14, R17: 120; 0805
R15, R16: 120; R0603
R18, R19, R20, R21, R22, R23: 0; 0805
S0, S1, S2, S3, S4, S5, S6, S7: M02PTH; 1X02
SURFACE: RJ45-8PTH; RJ45-8
T1, T2, T3, T4: BCV46; SOT23-BEC
U1: TLC5916_PW_16; PW16
U5: LTC1690SOIC8; SOIC8
V1: Video_1; 1X04
V2: Video_2; 1X04
V3: Video_3; 1X04
V4: Video_4; 1X04
VIDEO_MUX_1, VIDEO_MUX_2: BA765SOIC8; SOIC8
X1: TSW-125-02-S-D-RA

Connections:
+3V3: IC1.8 (VCC), IMU.4, POWER_IN.2, R2.2, R5.2, R8.2, R11.2, R21.2, T1.E, T2.E, T3.E, T4.E, U1.16 (VDD), X1.47
+3V3_: P2.45, P2.46, R19.2, R21.1, R23.2
+5V: C17.1, C22.2, C44.1, C45.1, C50.1, POWER_IN.3, R20.2, U5.1 (VCC), VIDEO_MUX_1.6 (VCC), VIDEO_MUX_2.6 (VCC), X1.45
+5V_: P2.47, P2.48, R18.2, R20.1, R22.2
+12V: POWER_IN.4, S0.1, S1.1, S2.1, S3.1, S4.1, S5.1, S6.1, S7.1, V1.3, V2.3, V3.3, V4.3
A: R16.1, SURFACE.8, U5.8 (A)
B: R16.2, SURFACE.7, U5.7 (B)
BOOT0: P2.29
COUNTER1: P1.44, X1.17
COUNTER2: P1.43, X1.15
DE_6: IC1.3 (DE), P2.5
FUSE_BLOWN: P1.24, PS_IN.1
GND: C1.2, C17.2, C22.1, C44.2, C45.2, C50.2, H2O1.1, H202.1, H203.1, H204.1, IC1.5 (GND), IMU.3, P1.1, P1.2, P1.45, P1.49, P1.50, P2.1, P2.2, P2.49, P2.50, POWER_IN.1, R3.1, R6.1, R9.1, R12.1, R13.2, U1.1 (GND), U5.4 (GND), V1.4, V2.4, V3.4, V4.4, VIDEO_MUX_1.8 (GND_1), VIDEO_MUX_2.8 (GND_1), X1.49
GND_: P1.27
H2O_DEC1: H2O1.2, R7.1, R8.1
H2O_DEC2: H202.2, R1.1, R2.1
H2O_DEC3: H204.2, R10.1, R11.1
H2O_DEC4: H203.2, R4.1, R5.1
H20_ALERT: P2.16, R3.2, R6.2, R9.2, R12.2, T1.C, T2.C, T3.C, T4.C
I2C1_SCL: IMU.1, P2.31
I2C1_SDA: IMU.2, P2.28
MOTOR_DIR: P2.26, X1.25
MOTOR_PWM: P1.25, X1.19
MOTOR_SELECT0: P1.23, X1.21
MOTOR_SELECT1: P1.26, X1.23
unnamed: R1.2, T1.B
unnamed: R4.2, T2.B
unnamed: R7.2, T3.B
unnamed: R10.2, T4.B
unnamed: IC1.7 (B), M1.1, M2.1, M3.1, M4.1, M5.1, M6.1, M7.1, M8.1, R14.2, R17.2
unnamed: C32.2, VIDEO_MUX_1.1 (IN_1)
unnamed: C41.1, VIDEO_MUX_1.3 (IN_2)
unnamed: S0.2, U1.5 (*OUT0)
unnamed: S1.2, U1.6 (*OUT1)
unnamed: S2.2, U1.7 (*OUT2)
unnamed: S3.2, U1.8 (*OUT3)
unnamed: C42.2, VIDEO_MUX_2.1 (IN_1)
unnamed: R13.1, U1.15 (R-EXT)
unnamed: C1.1, U1.14 (SDO)
unnamed: S7.2, U1.12 (*OUT7)
unnamed: S6.2, U1.11 (*OUT6)
unnamed: S5.2, U1.10 (*OUT5)
unnamed: S4.2, U1.9 (*OUT4)
unnamed: C43.1, VIDEO_MUX_2.3 (IN_2)
unnamed: IC1.6 (A), M1.2, M2.2, M3.2, M4.2, M5.2, M6.2, M7.2, M8.2, R14.1, R17.1
NC: P1.4
NC1: VIDEO_MUX_1.5 (NC)
NRST: P1.46
PA0: P1.40
PA3: P1.37
PA5: P1.35
PA6: P1.34
PA7: P1.33
PA8: P2.7
PA9: P2.8
PA10: P2.9
PA13: P2.10
PA14: P2.11
PA15: P2.12
PB2/BOOT1: P1.28
PB3: P2.24
PB4: P2.25
PB6: P2.27
PB9: P2.32
PB11: P1.15
PB12: P1.16
PB13: P1.13
PB14: P1.14
PC2: P1.42
PC3: P1.41
PC4: P1.32
PC10: P2.13
PC13: P2.40
PC14: P2.41
PC15: P2.42
PD1: P2.17
PD4: P2.20
PD5: P2.21
PD7: P2.23, X1.29
PD8: P1.12
PD9: P1.9
PD10: P1.10
PD11: P1.7
PD12: P1.8
PD13: P1.5
PD14: P1.6
PD15: P1.3
PE0: P2.33
PE1: P2.34
PE2: P2.35, X1.31
PE3: P2.36
PE4: P2.37, X1.33
PE5: P2.38
PE6: P2.39, X1.35
PE11: P1.21
PE12: P1.22
PE13: P1.19
PE14: P1.20
PE15: P1.17
PH0: P2.43
PH1: P2.44
PS1: P1.29, PS_IN.2
PS2: P1.30, PS_IN.3
PS3: P1.31, PS_IN.4
PS4: P1.36, PS_IN.5
PS5: P1.39, PS_IN.6
RE_6: IC1.2 (RE/), P2.6
RX_2: P2.22, U5.2 (R)
RX_6: IC1.1 (RO), P2.4
SHIFT_CLK: P1.18, U1.3 (CLK)
SHIFT_DATA: P1.11, U1.2 (SDI)
SHIFT_LE: P2.19, U1.4 (LE(ED1))
SHIFT_OE: P2.18, U1.13 (*OE(ED2))
TX_2: P1.38, U5.3 (D)
TX_6: IC1.4 (DI), P2.3
VDD: P1.47, P1.48, R22.1, R23.1
VDD_: P2.30, R18.1, R19.1
V_1: SURFACE.3, VIDEO_MUX_1.7 (OUT)
V_2: SURFACE.1, VIDEO_MUX_2.7 (OUT)
V_CTL_1: P2.14, VIDEO_MUX_1.2 (CTL)
V_CTL_2: P2.15, VIDEO_MUX_2.2 (CTL)
V_GND: SURFACE.2, SURFACE.4, V1.1, V2.1, V3.1, V4.1, VIDEO_MUX_1.4 (GND), VIDEO_MUX_2.4 (GND)
V_IN1: C32.1, V1.2
V_IN2: C41.2, V2.2
V_IN3: C42.1, V3.2
V_IN4: C43.2, V4.2
Y: R15.2, SURFACE.5, U5.5 (Y)
Z: R15.1, SURFACE.6, U5.6 (Z)

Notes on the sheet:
RS485 Block
This is the MAX3486E

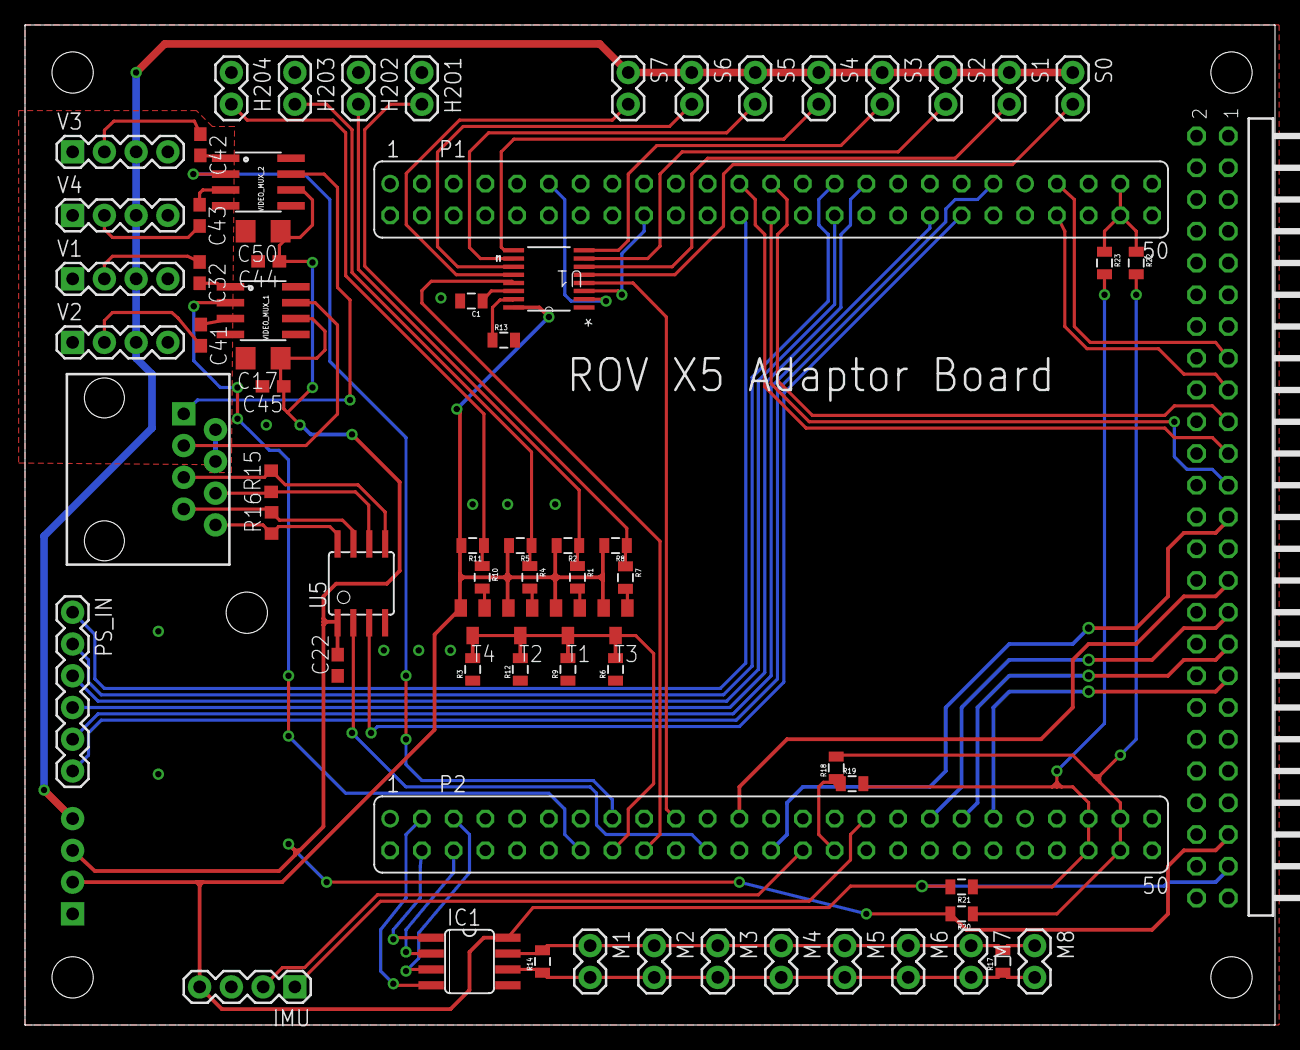
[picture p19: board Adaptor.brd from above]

Board: 2 copper layers, 100.0 x 80.0 mm, 78 parts (1 on the bottom side), 74 nets.

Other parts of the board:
U$1, U$2, U$3, U$4, U$5: STAND-OFF

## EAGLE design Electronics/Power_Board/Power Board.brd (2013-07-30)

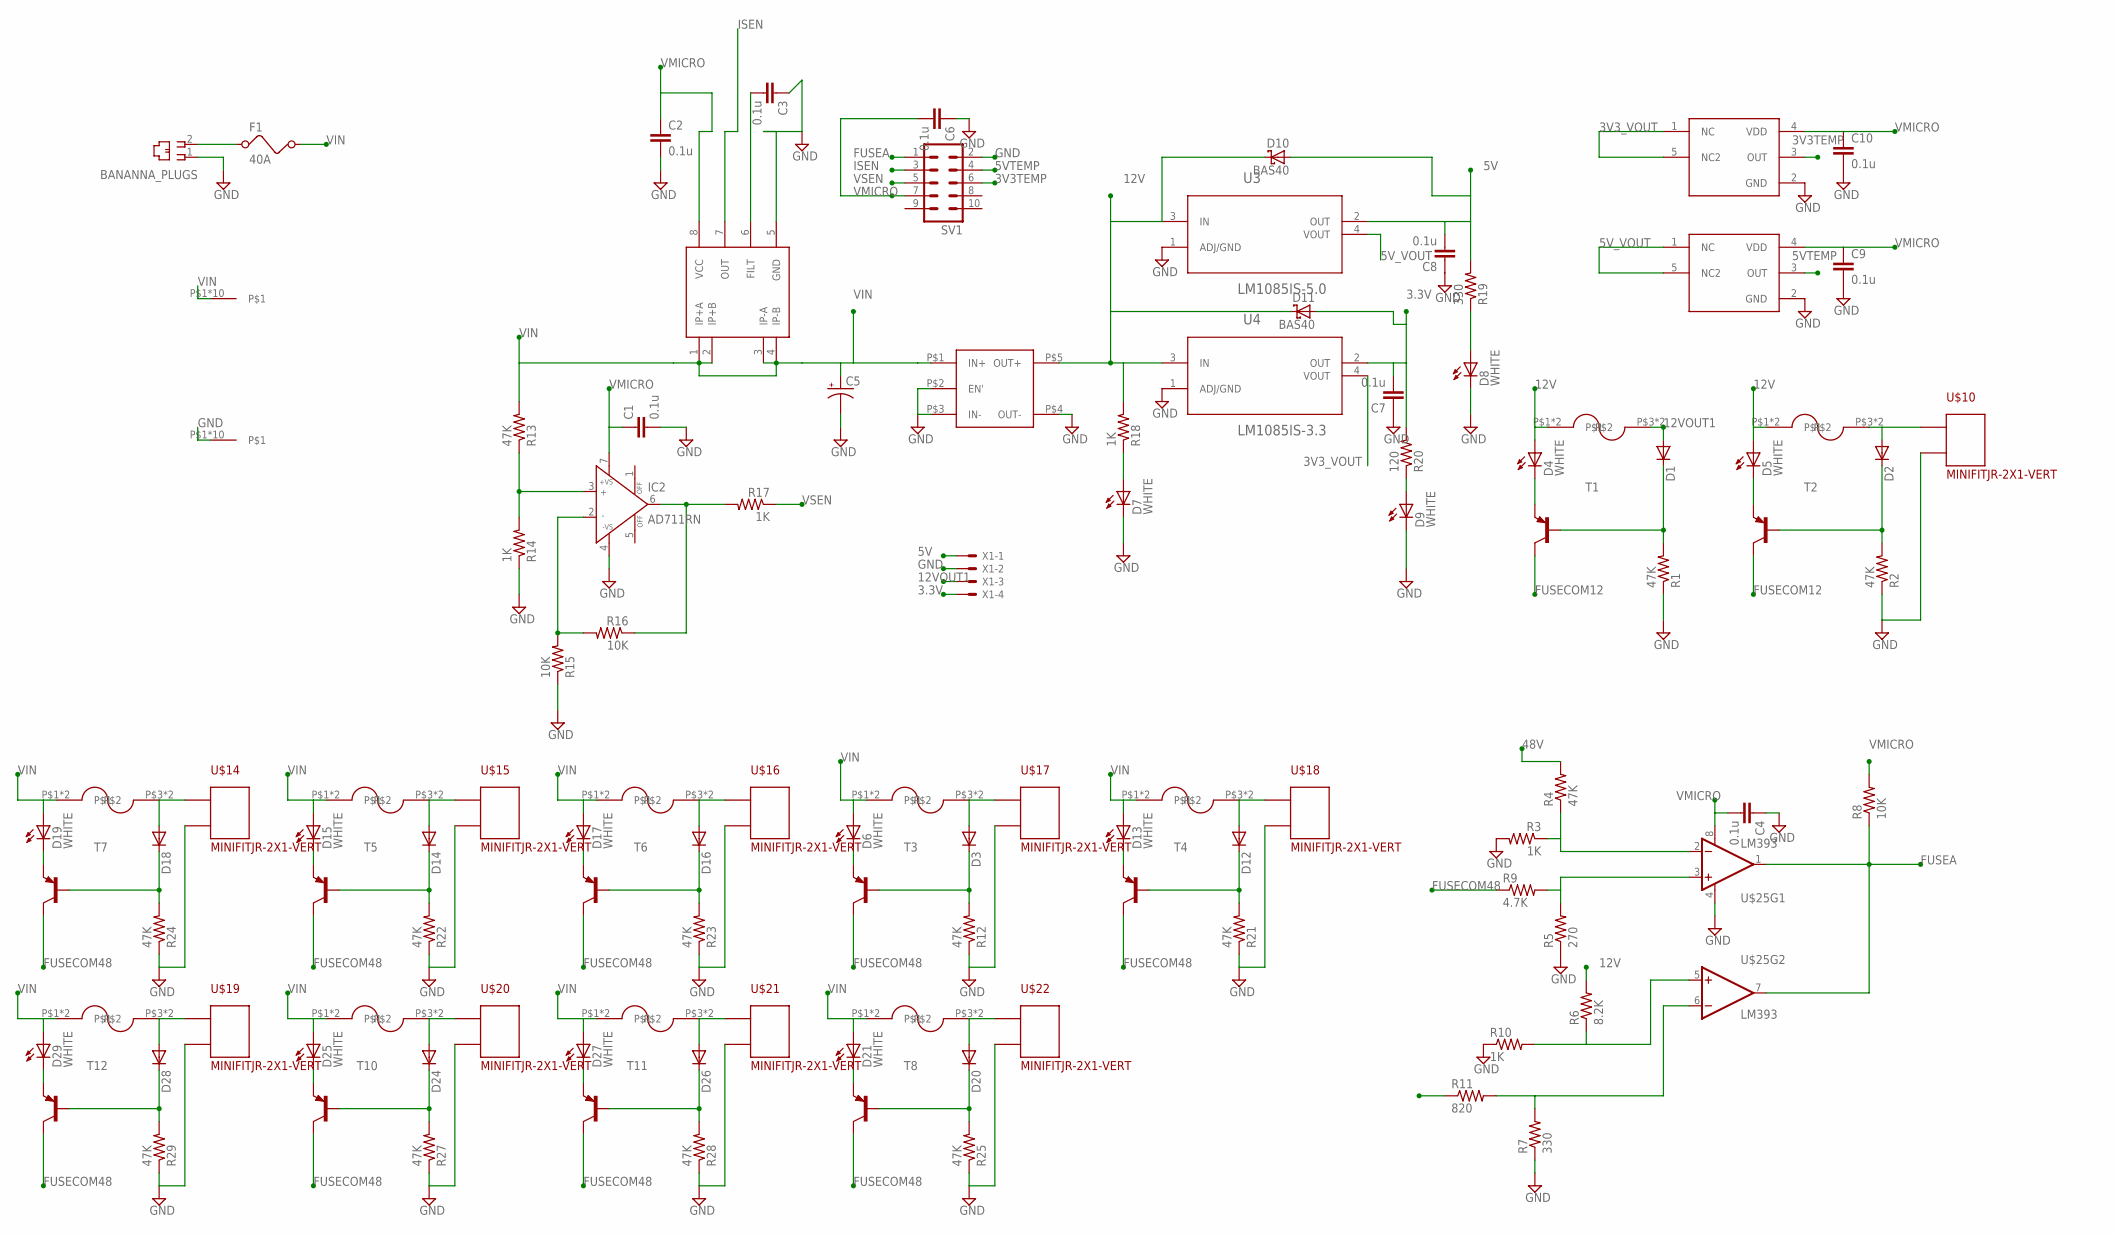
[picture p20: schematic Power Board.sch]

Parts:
BANANNA_PLUGS: 520470-4
C1, C2, C3, C4, C6, C7, C8, C9, C10: 0.1u; 0805
C5: CPOL-USE10-30; EB30D
D1, D2, D3, D12, D14, D16, D18, D20, D24, D26, D28: DIODEHV; DIODE-HV
D4, D5, D6, D7, D8, D9, D13, D15, D17, D19, D21, D25, D27, D29: WHITE; LED-1206
D10, D11: BAS40; SOT23
F1: 40A; FUSE
IC2: AD711RN; SO8
R1, R2, R4, R12, R13, R21, R22, R23, R24, R25, R27, R28, R29: 47K; 0805
R3, R10, R14, R17, R18: 1K; 0805
R5: 270; 0805
R6: 8.2K; 0805
R7, R19: 330; 0805
R8, R15, R16: 10K; 0805
R9: 4.7K; 0805
R11: 820; 0805
R20: 120; 0805
SV1: MA05-2
T1, T2, T3, T4, T5, T6, T7, T8, T10, T11, T12: BC856BLT1-PNP-SOT23-BEC; SOT23-BEC
U3: LM1085IS-5.0; TO254P1435X457-3N
U4: LM1085IS-3.3; TO254P1435X457-3N
U$1: SQE48T20120; BRICK
U$2, U$3, U$4, U$5, U$6, U$7, U$8, U$9, U$11, U$12, U$13: FUSEHOLDER3557-2
U$10, U$14, U$15, U$16, U$17, U$18, U$19, U$20, U$21, U$22: MINIFITJR-2X1-VERT; 5566-02B
U$25: LM393; SO08
U$26, U$27: MCP9700T; SOT353
U$30, U$31: SCREW_TERM; TERMINAL
U$32: ACS713; SOP08
X1: KK-156-4

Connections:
3.3V: C7.2, D11.1 (A), R20.2, U4.2 (OUT), X1.4
3V3TEMP: SV1.6, U$27.3 (OUT)
3V3_VOUT: U4.4 (VOUT), U$27.1 (NC), U$27.5 (NC2)
5V: C8.2, D10.1 (A), R19.2, U3.2 (OUT), X1.1
5VTEMP: SV1.4, U$26.3 (OUT)
5V_VOUT: U3.4 (VOUT), U$26.1 (NC), U$26.5 (NC2)
12V: D4.A, D5.A, D10.3 (C), D11.3 (C), R6.2, R18.2, U3.3 (IN), U4.3 (IN), U$1.P$5 (OUT+), U$3.P$1, U$3.P$2, U$4.P$1, U$4.P$2
12VOUT1: D1.A, U$4.P$3, U$4.P$4, X1.3
48V: R4.2
FUSEA: R8.1, SV1.1, U$25.1 (OUT), U$25.7 (OUT)
FUSECOM12: R11.1, T1.C, T2.C
FUSECOM48: R9.1, T3.C, T4.C, T5.C, T6.C, T7.C, T8.C, T10.C, T11.C, T12.C
GND: BANANNA_PLUGS.1, C1.2, C2.2, C3.1, C4.1, C5.-, C6.1, C7.1, C8.1, C9.2, C10.2, D7.C, D8.C, D9.C, IC2.4 (-VS), R1.1, R2.1, R3.2, R5.1, R7.1, R10.1, R12.1, R14.1, R15.1, R21.1, R22.1, R23.1, R24.1, R25.1, R27.1, R28.1, R29.1, SV1.2, U3.1 (ADJ/GND), U4.1 (ADJ/GND), U$1.P$2 (EN'), U$1.P$3 (IN-), U$1.P$4 (OUT-), U$10.P$2, U$14.P$2, U$15.P$2, U$16.P$2, U$17.P$2, U$18.P$2, U$19.P$2, U$20.P$2, U$21.P$2, U$22.P$2, U$25.4 (V-), U$26.2 (GND), U$27.2 (GND), U$31.P$1, U$31.P$2, U$31.P$3, U$31.P$4, U$31.P$5, U$31.P$6, U$31.P$7, U$31.P$8, U$31.P$9, U$31.P$10, U$32.5 (GND), X1.2
ISEN: SV1.3, U$32.7 (OUT)
unnamed: R3.1, R4.1, U$25.2 (-IN)
unnamed: D2.A, U$3.P$3, U$3.P$4, U$10.P$1
unnamed: R5.2, R9.2, U$25.3 (+IN)
unnamed: R6.1, R10.2, U$25.5 (+IN)
unnamed: R7.2, R11.2, U$25.6 (-IN)
unnamed: D2.C, R2.2, T2.B
unnamed: D5.C, T2.E
unnamed: D3.A, U$2.P$3, U$2.P$4, U$17.P$1
unnamed: D3.C, R12.2, T3.B
unnamed: D6.C, T3.E
unnamed: D1.C, R1.2, T1.B
unnamed: D4.C, T1.E
unnamed: C3.2, U$32.6 (FILT)
unnamed: IC2.3 (IN+), R13.1, R14.2
unnamed: IC2.2 (IN-), R15.2, R16.2
unnamed: IC2.6 (OUT), R16.1, R17.2
unnamed: D7.A, R18.1
unnamed: D8.A, R19.1
unnamed: D9.A, R20.1
unnamed: D12.C, R21.2, T4.B
unnamed: D13.C, T4.E
unnamed: BANANNA_PLUGS.2, F1.1
unnamed: D12.A, U$5.P$3, U$5.P$4, U$18.P$1
unnamed: D14.C, R22.2, T5.B
unnamed: D15.C, T5.E
unnamed: D14.A, U$6.P$3, U$6.P$4, U$15.P$1
unnamed: D16.C, R23.2, T6.B
unnamed: D17.C, T6.E
unnamed: D16.A, U$7.P$3, U$7.P$4, U$16.P$1
unnamed: D18.C, R24.2, T7.B
unnamed: D19.C, T7.E
unnamed: D18.A, U$8.P$3, U$8.P$4, U$14.P$1
unnamed: D20.C, R25.2, T8.B
unnamed: D21.C, T8.E
unnamed: D20.A, U$9.P$3, U$9.P$4, U$22.P$1
unnamed: D24.C, R27.2, T10.B
unnamed: D25.C, T10.E
unnamed: D24.A, U$11.P$3, U$11.P$4, U$20.P$1
unnamed: D26.C, R28.2, T11.B
unnamed: D27.C, T11.E
unnamed: D26.A, U$12.P$3, U$12.P$4, U$21.P$1
unnamed: D28.C, R29.2, T12.B
unnamed: D29.C, T12.E
unnamed: D28.A, U$13.P$3, U$13.P$4, U$19.P$1
VIN: C5.+, D6.A, D13.A, D15.A, D17.A, D19.A, D21.A, D25.A, D27.A, D29.A, F1.2, R13.2, U$1.P$1 (IN+), U$2.P$1, U$2.P$2, U$5.P$1, U$5.P$2, U$6.P$1, U$6.P$2, U$7.P$1, U$7.P$2, U$8.P$1, U$8.P$2, U$9.P$1, U$9.P$2, U$11.P$1, U$11.P$2, U$12.P$1, U$12.P$2, U$13.P$1, U$13.P$2, U$30.P$1, U$30.P$2, U$30.P$3, U$30.P$4, U$30.P$5, U$30.P$6, U$30.P$7, U$30.P$8, U$30.P$9, U$30.P$10, U$32.1 (IP+A), U$32.2 (IP+B), U$32.3 (IP-A), U$32.4 (IP-B)
VMICRO: C1.1, C2.1, C4.2, C6.2, C9.1, C10.1, IC2.7 (+VS), R8.2, SV1.7, U$25.8 (V+), U$26.4 (VDD), U$27.4 (VDD), U$32.8 (VCC)
VSEN: R17.1, SV1.5

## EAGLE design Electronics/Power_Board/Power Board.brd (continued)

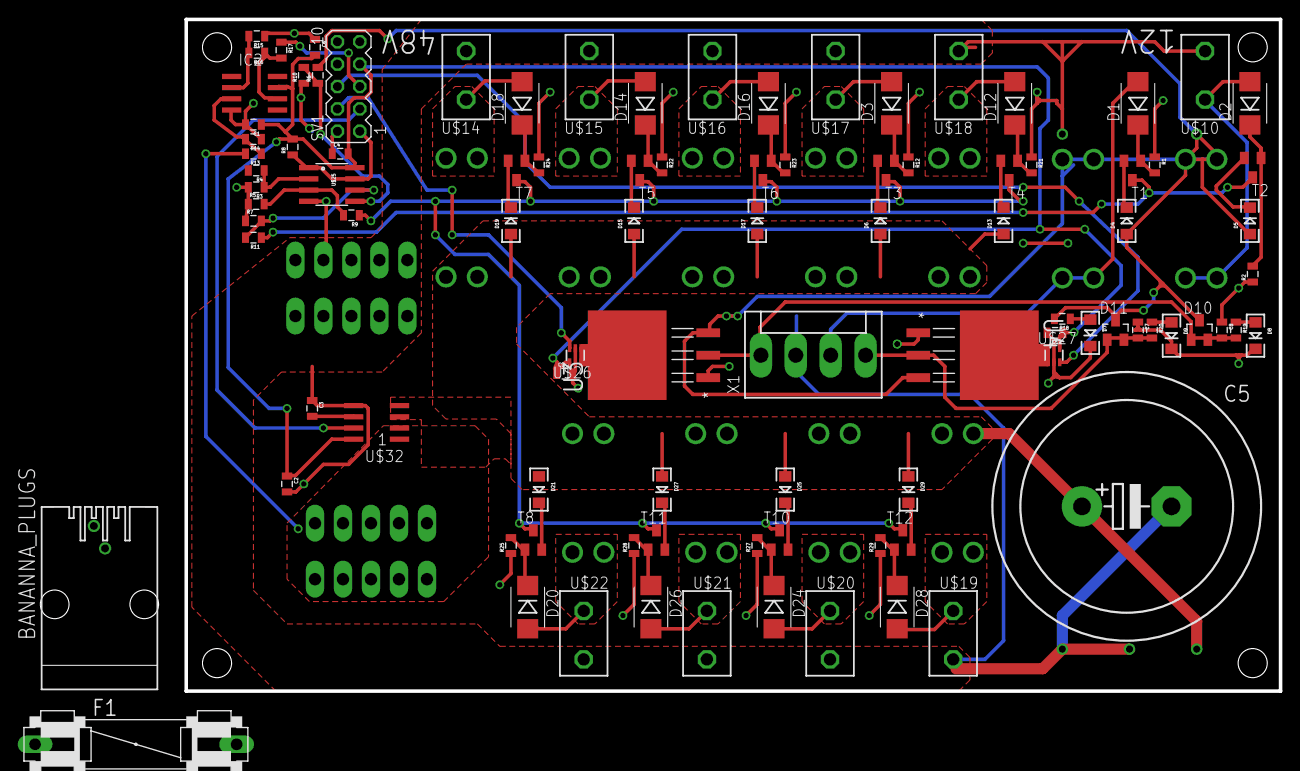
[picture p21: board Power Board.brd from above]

Board: 2 copper layers, 124.1 x 76.2 mm, 115 parts (1 on the bottom side), 60 nets.

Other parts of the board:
U$23, U$24, U$28, U$29: STAND-OFF

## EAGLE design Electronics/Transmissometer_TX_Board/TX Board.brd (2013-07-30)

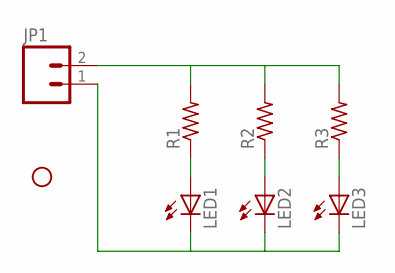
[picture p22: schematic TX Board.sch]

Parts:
JP1: M02PTH4; 1X02_XTRA_BIG
JP2: STAND-OFF
LED1, LED2, LED3: LED-FKIT-1206; FKIT-LED-1206
R1, R2, R3: R-US_M1206; M1206

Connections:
GND: JP1.2, R1.2, R2.2, R3.2
unnamed: LED1.A, R1.1
unnamed: LED2.A, R2.1
unnamed: LED3.A, R3.1
unnamed: JP1.1, LED1.C, LED2.C, LED3.C

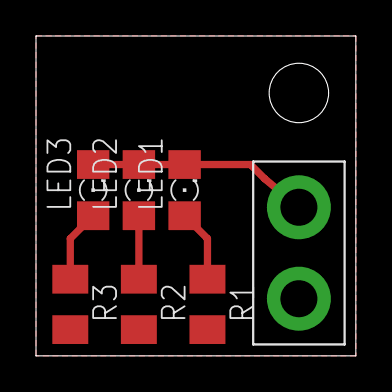
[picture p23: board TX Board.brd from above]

Board: 2 copper layers, 17.8 x 17.8 mm, 8 parts (0 on the bottom side), 5 nets.

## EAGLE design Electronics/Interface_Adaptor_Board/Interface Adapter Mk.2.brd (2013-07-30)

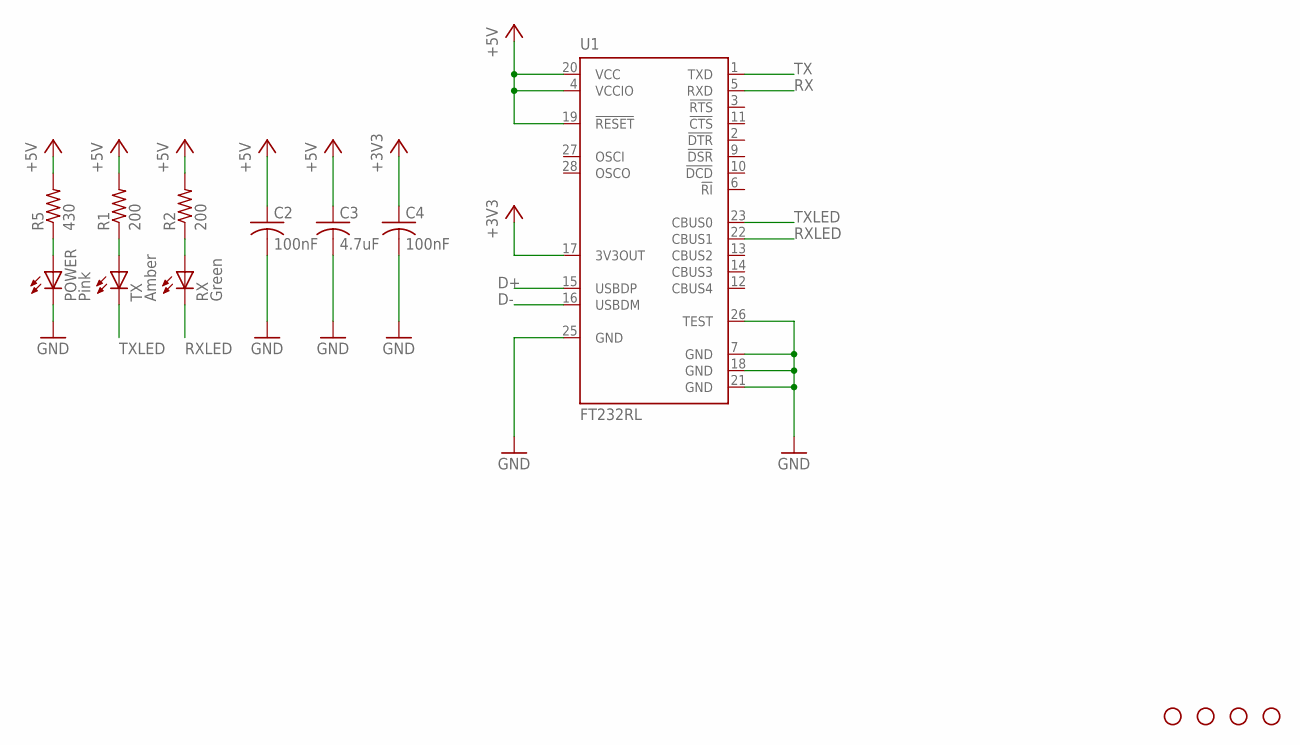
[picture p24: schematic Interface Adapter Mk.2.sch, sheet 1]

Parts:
C2, C4: 100nF; C0603
C3: 4.7uF; C0603
JP1, JP2, JP3, JP4: STAND-OFF
POWER: Pink; LED-0603
R1, R2: 200; R0603
R5: 430; R0603
RX: Green; LED-0603
TX: Amber; LED-0603
U1: FT232RL; SSOP28

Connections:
+3V3: C4.1, U1.17 (3V3OUT)
+5V: C2.1, C3.1, R1.2, R2.2, R5.2, U1.4 (VCCIO), U1.19 (!RESET), U1.20 (VCC); also elsewhere on the board
D+: U1.15 (USBDP); also elsewhere on the board
D-: U1.16 (USBDM); also elsewhere on the board
GND: C2.2, C3.2, C4.2, POWER.C, U1.7 (GND), U1.18 (GND), U1.21 (GND), U1.25 (GND), U1.26 (TEST); also elsewhere on the board
unnamed: R1.1, TX.A
unnamed: R2.1, RX.A
unnamed: POWER.A, R5.1
RX: U1.5 (RXD); also elsewhere on the board
RXLED: RX.C, U1.22 (CBUS1)
TX: U1.1 (TXD); also elsewhere on the board
TXLED: TX.C, U1.23 (CBUS0)


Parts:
C5: 100nF; C0603
R3, R4: 100; R0603
U2: LTC1690; SOIC-8

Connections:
+5V: C5.1, U2.1 (VCC); also elsewhere on the board
A: R3.2, U2.8 (A); also elsewhere on the board
B: R3.1, U2.7 (B); also elsewhere on the board
GND: C5.2, U2.4 (GND); also elsewhere on the board
RX: U2.2 (RX); also elsewhere on the board
TX: U2.3 (TX); also elsewhere on the board
Y: R4.1, U2.5 (Y); also elsewhere on the board
Z: R4.2, U2.6 (Z); also elsewhere on the board


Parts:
C1: 10nF; C0603
J1: VID1; RCA
J2: VID2; RCA
L1, L2: FERRITE; 0603
U$2: RJ45-8PTH; RJ45-8
X1: USBPTH; USB-B-PTH

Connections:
+5V: L1.1; also elsewhere on the board
A: U$2.8; also elsewhere on the board
B: U$2.7; also elsewhere on the board
D+: X1.D+; also elsewhere on the board
D-: X1.D-; also elsewhere on the board
GND: C1.2, L2.2, X1.GND, X1.P$1, X1.P$2; also elsewhere on the board
unnamed: C1.1, L1.2, X1.VBUS
VGND: J1.BARREL (GND), J1.SPRING (GNDBREAK), J2.BARREL (GND), J2.SPRING (GNDBREAK), L2.1, U$2.2, U$2.4
VID1: J1.BREAK (PWR), U$2.3
VID2: J2.BREAK (PWR), U$2.1
Y: U$2.5; also elsewhere on the board
Z: U$2.6; also elsewhere on the board


Board: 2 copper layers, 63.5 x 30.5 mm, 26 parts (0 on the bottom side), 20 nets.

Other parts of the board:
U$1: OSHW-LOGO-M

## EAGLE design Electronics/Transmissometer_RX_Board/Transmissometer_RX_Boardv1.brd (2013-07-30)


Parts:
C1: 0.1u; C0805
JP1: PINHD-1X3; 1X03
R1: 1K; R0805
R2: NP; R0805
U1: AD8628ARZ-REEL7; SOIC127P600X175-8N
U$1: TEMPT1020

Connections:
+5V: C1.2, JP1.1, R1.2, U1.7 (V+)
GND: C1.1, JP1.3, U1.4 (V-), U$1.P$1
unnamed: R1.1, R2.1, U1.3 (+IN), U$1.P$2
OUT: JP1.2, R2.2, U1.2 (-IN), U1.6 (OUT)

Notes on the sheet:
Hard Solder?


Board: 2 copper layers, 17.8 x 16.8 mm, 7 parts (0 on the bottom side), 4 nets.

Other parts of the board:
U$2: STAND-OFF

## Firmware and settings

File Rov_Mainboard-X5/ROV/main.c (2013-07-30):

#include "functions.h"
volatile FIFO_TypeDef U2Rx, U2Tx, U6Rx, U6Tx;
volatile uint8_t flag=0;


int main(void){
  
  SystemInit();
  //ShiftInit();
  //LedInit();
  Usart6Init();
  Usart2Init();
  Motor1Init();
  Motor2Init();
  Motor3Init();
  Motor4Init();
  Motor5Init();
  Motor6Init();
  Motor7Init();
  Motor8Init();
  //MotorSet(1,1,0); 
  //MotorSet(2,1,20);
  //MotorSet(3,1,30);
  //MotorSet(4,1,40);
  //MotorSet(5,1,100);
  //MotorSet(6,1,200);
  //MotorSet(7,1,70);
  //MotorSet(8,1,700);
  //MotorSet(1,1,50);
  //GPIO_SetBits(LED_0_PORT, LED_0_PIN); 
  while(1){
      MotorControl(U2Rx.buff[1],U2Rx.buff[2],U2Rx.buff[3],U2Rx.buff[4],U2Rx.buff[5],U2Rx.buff[6],U2Rx.buff[7],U2Rx.buff[8]);
      //MotorSet(1,1,1); 
      ShiftControl(U2Rx.buff[9], U2Rx.buff[10],U2Rx.buff[11], U2Rx.buff[12]);
     // ShiftControl(1,0,1,1);
     // GPIO_SetBits(LED_3_PORT, LED_3_PIN); 
  }
  
}
 
                
                
//CODE TO UPDATE ADDRESS                
/*
   GPIO_SetBits(LED_2_PORT, LED_2_PIN); 
   delay(33333333);
   UpdateAddress(0x55, 0x54);
   GPIO_ResetBits(LED_2_PORT, LED_2_PIN);
   GPIO_SetBits(LED_3_PORT, LED_3_PIN);
*/
  
//CODE TO RESET MOTOR
/*                
   GPIO_SetBits(LED_0_PORT, LED_0_PIN); 
   delay(33333333);
   ResetMotorAddress();
   GPIO_ResetBits(LED_0_PORT, LED_0_PIN);
   GPIO_SetBits(LED_2_PORT, LED_2_PIN);      
*/               
      
//CODE TO REQUEST STATUS AND SPIN MOTOR
///*
    //delay(33333333);
    //MotorControl(0x51, 0x80);
    
      
      
   /*
            RequestStatus(0x51);
            RequestStatus(0x55);
            MotorControl(0x51, 0xB4);
            MotorControl(0x55, 0xB4);            
            GPIO_ResetBits(USART6_ENABLE_PORT, USART6_ENABLE_PIN);
 	    GPIO_ResetBits(USART6_DISABLE_PORT, USART6_DISABLE_PIN);
            GPIO_SetBits(LED_0_PORT, LED_0_PIN);
            delay(33333333);
            GPIO_ResetBits(LED_0_PORT, LED_0_PIN);
            GPIO_SetBits(LED_2_PORT, LED_2_PIN);
            MotorControl(0x51, 0x80);
            MotorControl(0x55, 0x80);
            delay(33333333);
            GPIO_ResetBits(LED_2_PORT, LED_2_PIN);
      */
      
	
//*/    

/*	while(1){
          


		GPIO_SetBits(LED_1_PORT, LED_1_PIN);
                //USART_SendData(USART6, 0x12);
                delay(10000000);
                GPIO_ResetBits(LED_1_PORT, LED_1_PIN);
               // USART_SendData(USART6, 0x13);
                delay(10000000);
                
                
		/

		//LF, RF, LB, RB, Nothing , RFV, LBV, RBV, nothing, LFV
		MotorControl(U3Rx.buff[1],U3Rx.buff[2],U3Rx.buff[3],U3Rx.buff[4],0,U3Rx.buff[6],U3Rx.buff[7],U3Rx.buff[8],0,U3Rx.buff[5]);
		ShiftControl(U3Rx.buff[9], U3Rx.buff[10],U3Rx.buff[11], U3Rx.buff[12]);
		MUXControl(U3Rx.buff[13],U3Rx.buff[14]);
		LedControl(U3Rx.buff[15],U3Rx.buff[16],U3Rx.buff[17]);
	
		//MotorControl(0,0,0,100,0,0,0,0,0,0);
		
		//use usart, not buffer!
		
		USART_SendData(USART3, 0x12);
		delay(170000);
	
		//send data back here!

		if(GPIO_ReadInputDataBit(INDUCTION_PORT, INDUCTION_PIN) == (uint8_t)Bit_SET){
			USART_SendData(USART3, 0x30);
			delay(170000);
		}else{
			USART_SendData(USART3, 0x31);
			delay(170000);
		}
		USART_SendData(USART3, 0x13);
		delay(170000);
                /
	}
*/

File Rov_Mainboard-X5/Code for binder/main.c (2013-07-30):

#include "functions.h"
volatile FIFO_TypeDef U2Rx, U2Tx, U6Rx, U6Tx;
volatile uint8_t flag=0;


int main(void){

        SystemInit();
        
		LedInit();
        Usart6Init();
		
	while(1){

		//LF, RF, LB, RB, Nothing , RFV, LBV, RBV, nothing, LFV
		MotorControl(U2Rx.buff[1],U2Rx.buff[2],U2Rx.buff[3],U2Rx.buff[4],0,U2Rx.buff[6],U2Rx.buff[7],U2Rx.buff[8],0,U2Rx.buff[5]);
		ShiftControl(U2Rx.buff[9], U2Rx.buff[10],U2Rx.buff[11], U2Rx.buff[12]);
		MUXControl(U2Rx.buff[13],U2Rx.buff[14]);
	}
}

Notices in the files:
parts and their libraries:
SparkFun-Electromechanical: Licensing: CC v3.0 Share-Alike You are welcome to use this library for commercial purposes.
